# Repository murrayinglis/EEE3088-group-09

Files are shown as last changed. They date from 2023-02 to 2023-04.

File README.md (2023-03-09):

# EEE3088-group-09
Electrical Engineering Design Process

Group members: 
-Murray Inglis INGMUR002
-Tinashe Timba TMBTIN004
-Ankush Chohan CHHANK001

Description:
The analogue sensor is a battery sensor that will record the voltage of the battery via communicating with the STM ADC.
The digital sensor is a light sensor chip that communicates using I2C with the STM.

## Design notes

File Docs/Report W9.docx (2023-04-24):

EEE3088F 2023

Interim Design Report

Group 09 Light Sensor HAT

Ankush Chohan (CHHANK001)

Tinashe Timba (TMBTIN004)

Murray Inglis (INGMUR002)

23/04/2023

# 1 Executive Summary

The following report documents the design process and current design of a Light Sensor Discovery board HAT intended for use as a quality checker in glass manufacturing, water purification, and farming processes. Section 2 outlines these use cases in more detail along with the block system designed to meet the basic requirements. The schematic designs for the sub-modules can be found here: https://github.com/murrayinglis/EEE3088-group-09/tree/main/PCB/SCHEMATICS.

Technical specifications outlining the system requirements of the design and the related power consumption details are included in Section 3. An Agile process was followed to refine the project at each stage. Given the design, the device is capable of monitoring light intensity levels and managing the battery-powered system to ensure safety and long use.

For further details including licensing, reusing, and deploying; see the Github repository https://github.com/murrayinglis/EEE3088-group-09/blob/main/LICENSE.

# 2 Introduction

The team has designed a digital light sensor that works in conjunction with the STM32 microcontroller. It can be used to detect and monitor light intensity throughout the day and this data can be stored externally and be analysed for determining the light intensity conditions at the sensor’s location. The sensor can provide information such as the maximum and minimum light intensity experienced during the day. By placing the sensor at various conditions, the recorded data can be used to find the optimum location for a specific use.

The HAT will also have an analogue sensor that will measure the battery percentage of the device. This value can then be displayed on LEDs that are mounted on the board.

User role/Scenario1:

In a water purification plant, the water can be run through a glass tube with a light on one side and a light sensor on the other. Depending on the amount of light that passes through the water, the water quality can be gauged.

- A compact device that can be mounted on existing machinery.
- High accuracy reading to be generated for quality control purposes.
- Cost-effective solution. The cost of producing 5 of these boards is below USD70.

User role/Scenario2:

The device can be used to measure the quality of glass in a glass production line. Depending on the

value of light intensity that passes through a pane of glass, the glass can be categorized.

- User-friendly design that does not require technical training for employees.
- Robust design with low maintenance costs. The cost of producing 5 of these boards is below USD70.
- Takes readings at a fast rate to minimalize delays in production (5Hz).

User role/Scenario3

The device can be used by subsistence farmers to find the optimal position in their plot to grow specific varieties of plants depending on the lighting conditions that these plants thrive in. In this case the device will be placed out-doors therefore the onboard battery and battery level sensor will be useful.

- The device must be battery-powered as it will be placed outdoors far away from a power
- supply.
- Easy to move and set up.
- Efficient power consumption design switches certain modules into sleep mode when they are not being used.

## 2.1 Project Subsystems Block Diagram

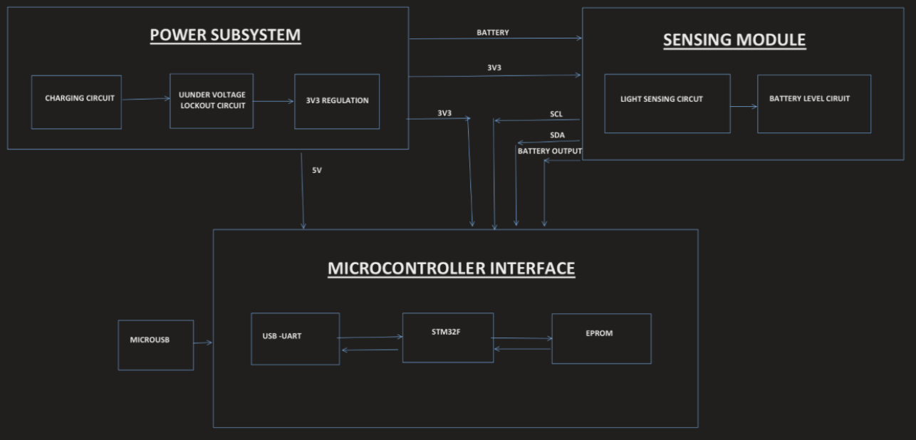
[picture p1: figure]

## 3 Specifications

## 3.1 Power subsystem submodule

Charging module:

IC used: TP4054-42

- Voltage input: 5V
- Voltage output to battery: 4.1V
- Current input: 0.5A
- Overcharge protection: regulates up to 18V down to 5V

Power supply to HAT:

3v3 Regulator IC used: AMS1117-3_3

- Voltage input from battery (4.1V-1V)
- Voltage output: 3.235V – 3.365V
- Current: 27mA
- Overcharge protection: regulates up to 18V down to 3.3V
- Schottky diode polarity protection
- Under voltage protection (1V lockout)

Conclusion:

Simulations of the under-voltage lockout circuit have shown lockout at around 1V which is too low a value for the HAT to operate. Additionally, the lockout level of the circuit is dependent on the load. Therefore, this circuit cannot be relied on until a physical test is done. The design, however is still safe due to the inclusion of intentional redundancy in the design. The under-voltage lockout circuit can be bypassed.

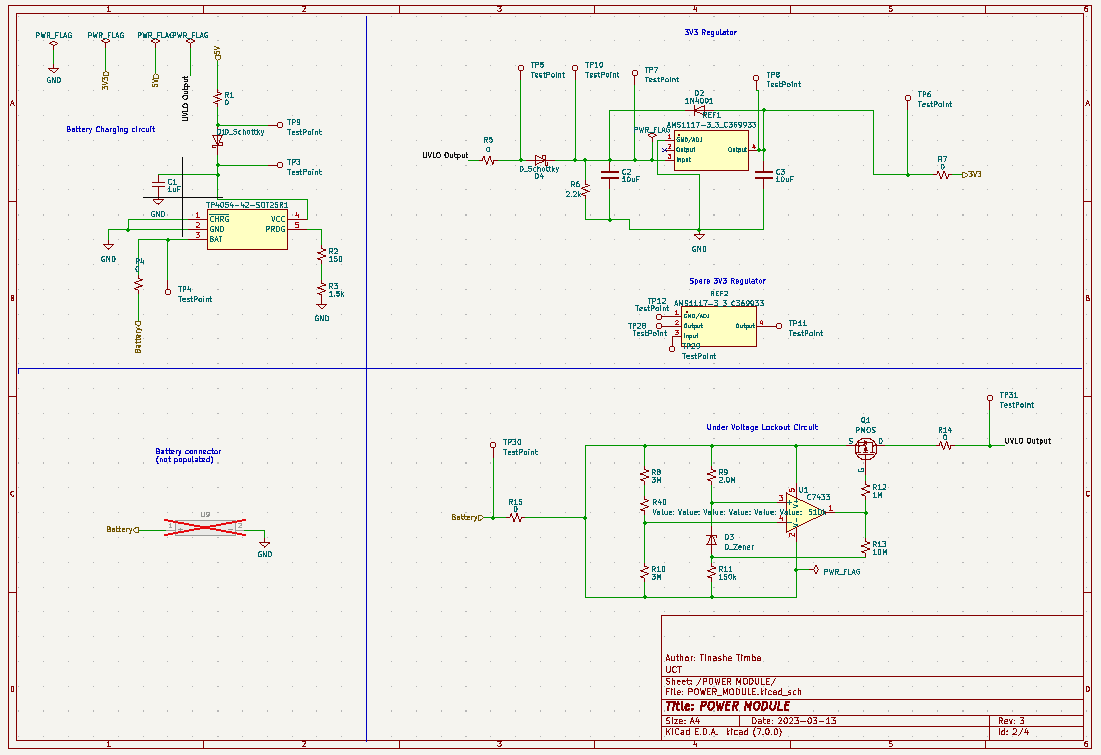
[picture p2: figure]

Figure 1: Power submodule https://github.com/murrayinglis/EEE3088-group-09/blob/main/PCB/SCHEMATICS/POWER_MODULE.kicad_sch.

## 3.2 Microcontroller interfacing submodule

Micro-usb:

- Name: USB 2.0 Surface Mount Female Micro-B SMD
- Part number: C404969
- Current rating: 1.8A
- Voltage rating: 30V

EEPROM:

IC used: AT24C256C-SSHL-T EEPROM

- Part number: C6482
- Operating voltage: 1.7V – 5.5V
- Operating read current: 1mA
- Operating write current: 3mA

USB to UART convertor:

IC used: CP2102-GMR

- Part number: C6568
- Operating voltage: 3V-3.6V
- Supply current: 200uA

Conclusion:

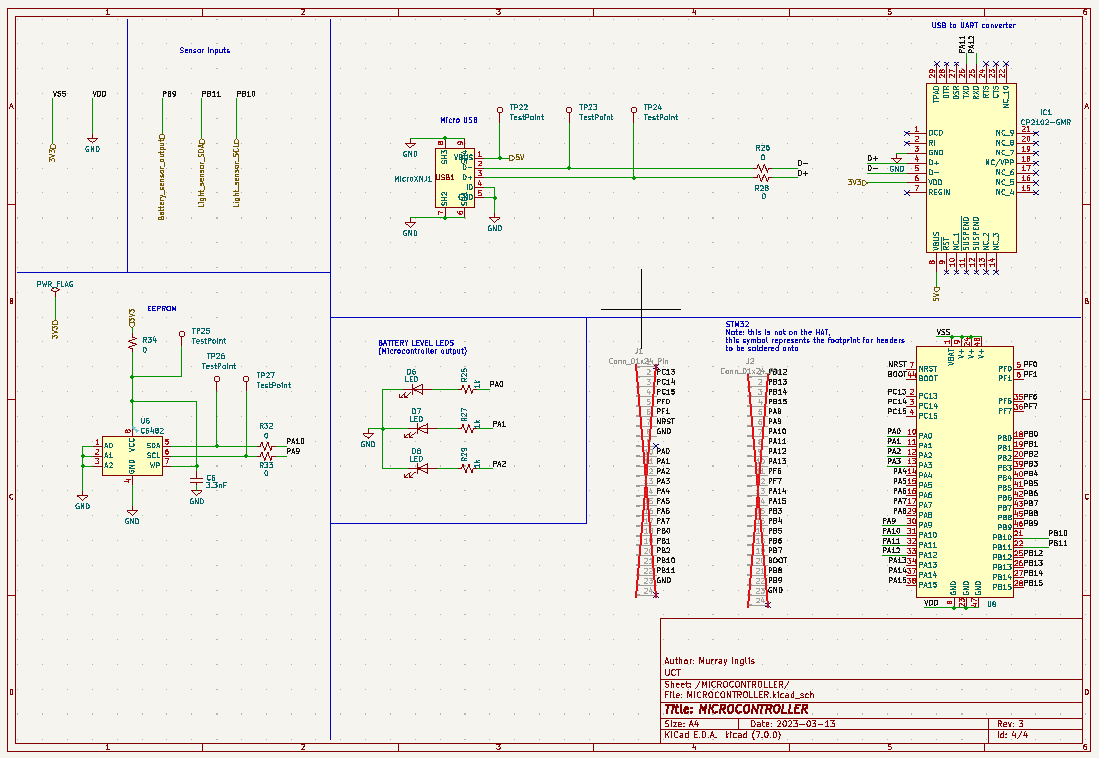
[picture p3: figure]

The team is satisfied with this submodule and believes that it has good design. There are no outstanding issues.

Figure 2: Microcontroller submodule https://github.com/murrayinglis/EEE3088-group-09/blob/main/PCB/SCHEMATICS/MICROCONTROLLER.kicad_sch

## 3.3 Sensing submodules

Digital optical sensor:

IC used: LTR-303ALS-01

- Supply voltage: 2.4V - 3.6V
- Interface bus supply voltage: 1.7V - 3.6V
- I2C Bus Input Pin High Voltage: 1.2V
- I2C Bus Input Pin Low Voltage: 0.6V
- Operating temperature: -30°C – 70°C
- Active supply current: 220uA
- Standby current: 5uA
- Initial startup time: 100ms
- Wakeup time from standby: 10ms

Analogue battery sensor:

- Input voltage from battery: 1V – 5V
- Output voltage: 0V - 2.5V
- Output current: 27mA

Conclusion:

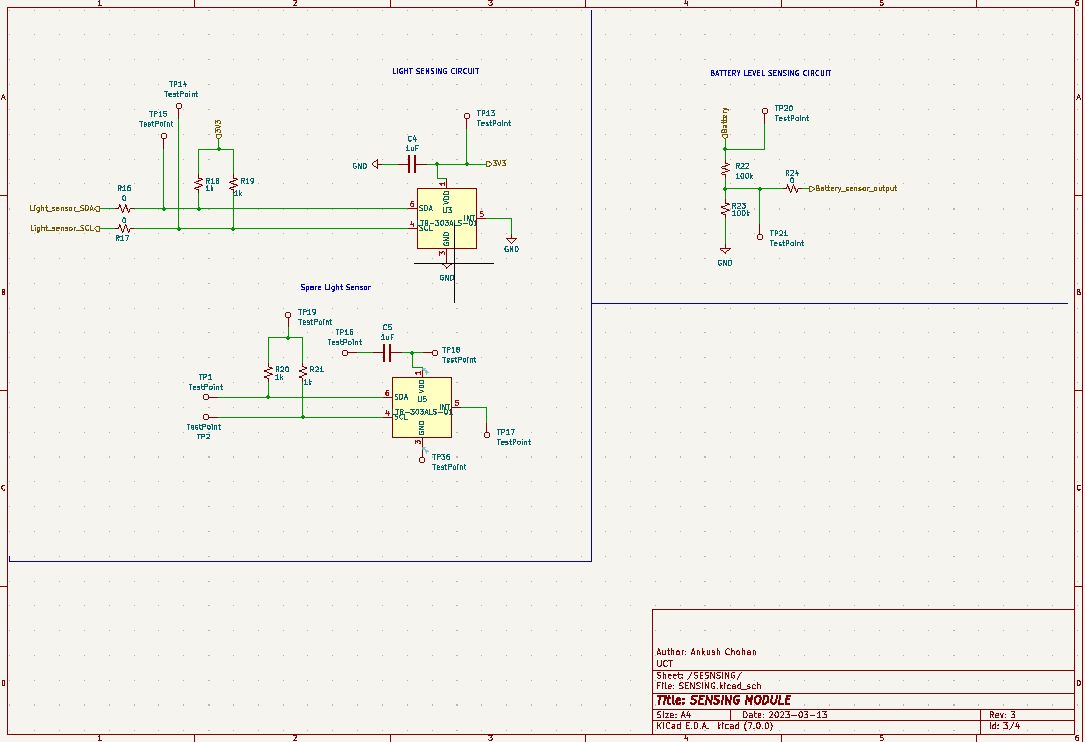
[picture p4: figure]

The team is satisfied with this submodule and believes that it has good design. There are no outstanding issues.

Figure 3: Sensing submodule https://github.com/murrayinglis/EEE3088-group-09/blob/main/PCB/SCHEMATICS/SENSING.kicad_sch.

# 4 Power Budgeting

## 4.1 Power submodule

Component | Supply Voltage (nominal V) | Minimum Current (mA) | Typical Current (mA) | Maximum Current (mA) | Minimum Power (mW) | Typical Power (mW) | Maximum Power (mW)
Battery charger (TP4054-42) | 5 | 0 | 0.150 | 0.500 | 0 | 0.75 | 2.5
Voltage regulator (AMS1117-3_3) | 4.8 | 900 | 1100 | 1500 | 4.32 | 5.28 | 7.2
Totals | | | | | 4.32 | 6.03 | 9.7

## 4.2 Microcontroller interfacing submodule

Component | Supply Voltage (nominal V) | Minimum Current (mA) | Typical Current (mA) | Maximum Current (mA) | Minimum Power (mW) | Typical Power (mW) | Maximum Power (mW)
FTDI (CP2102-GMR) | 3.3 | 0 | 20 | 26 | 0 | 66 | 85.8
EEPROM (AT24C256C) | 3.3 | 0 | 1 | 2 | 0 | 3.3 | 6.6
Totals | | | | | 0 | 69.3 | 92.1

## 4.3 Sensing submodules

Component | Supply Voltage (nominal V) | Minimum Current (mA) | Typical Current (mA) | Maximum Current (mA) | Minimum Power (mW) | Typical Power (mW) | Maximum Power (mW)
Light sensor (LTR-303ALS-01) | 3.3 | 0.005 | Not stated in the datasheet | 0.22 | 0.165 | NA | 0.726
Totals | | | | | 0.165 | | 0.726

Caveats:

For the battery sensor, there is no IC being used but power will be drawn by the voltage divider used to create a voltage for the STM32 ADC.

Additionally, the typical current for the light sensor IC was not stated in the datasheet, so the typical power could not be found.

4.4 System total

Submodule | Supply Voltage (nominal V) | Minimum Current (mA) | Typical Current (mA) | Maximum Current (mA) | Minimum Power (mW) | Typical Power (mW) | Maximum Power (mW)
PSU | 5 | | | | 4.32 | 6.03 | 9.7
Light sensor (LTR-303ALS-01) | 3.3 | 0.005 | N/A | 0.22 | 0.165 | NA | 0.726
Battery Level Sensor | 3.3 | 0 | - | - | - | - | -
Memory | 3.3 | 0 | 1 | 2 | 0 | 3.3 | 6.6
Microprocessor | 3.3 | - | - | 120 | - | - | 396
Totals | | | | | 4.485 | 9.33 | 413

# 5 Design Process

After brainstorming, the team settled on designing a HAT with a digital light sensor and an analogue battery level sensor. The decision was made due to the fact that the team believed this would be a simple and cost-effective approach to meet the basic requirements.

The team decided to use the LTR-303ALS-01 for the light sensor because it was one of the cheapest and had a large stock quantity. It also had clear application circuits.

The implementation of the battery level sensor was chosen to be a voltage divider to the STM32 ADC. This decision was made due to the implementation being simple and cheap.

The AT24C256C EEPROM was chosen because it was a basic part and had a large stock quantity.

The CP2102-GMR USB to UART converter (FTDI) chip was chosen because it was one of the cheapest USB to UART converters available on JLCPCB and it had a large stock quantity.

An inflection point the team encountered was that initially, the schematic included pin headers for the debugger, however after consultation with the assigned tutor, it was decided that it would be simpler and more effective to just use jumper cables to the debugger on the discovery board.

A problem that was encountered by the team was that all traces for the PCB were placed on the top layer. This led to a lack of space and an untidy board layout. Setting the bottom layer to a ground plane simplified this process, as well as using vias and tracks on the bottom plane.

During the design process, the team decided to include spare components on the HAT for redundancy. Seeing as the budget allowed for this and warnings were received that components from JLCPCB could be faulty or missing entirely.

# 6 Conclusion

In conclusion, the design requirements stated that a PCB with capabilities to handle and process information for 2 sensors where addressed by designing a HAT with a digital light-sensor (LTR-303ALS-01) and an analogue battery level sensor (voltage divider). These sensors were chosen as they were relatively simple and cost-effective to implement. The HAT works in conjunction with the STM32F microcontroller to perform the required tasks. Use cases for the HAT include product quality checking in glass manufacturing processes, and water purification processes as well as farming applications. The HAT takes in input from a USD which goes through a 3v3 regulator that supplies the rest of the components i.e the sensing module and microcontroller interface. Data is stored in the EPROM for reference and future use.

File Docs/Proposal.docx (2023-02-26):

Q1 Enviro sensing HAT Concept [5]

Describe what your HAT’s use case is, what it will attach to and in what scenario(s) someone would use it?

Light sensor that works in conjunction with the STM32 Board.

It can be used to detect and monitor light intensity throughout the day and this data can be stored externally and be analyzed for determining the light intensity conditions where the sensor is. This can provide information such as the maximum and minimum light intensity experienced during the day. By placing the sensor at various conditions, the recorded data can be used to find the optimum location for a specific use.

The HAT will also have a digital sensor which will measure the battery percentage of the device. This value can then be displayed on the LCD screen of the STM32 board.

Q2 Requirements [10]

The lecture discussed how one approach to capturing requirements is to think through the user stories that apply to a product/system/device. List 3 user stories that apply to your concept. These could be 3 different ways or reasons someone would use your HAT, eg 3 different situations it would be useful in, or even better would be if you can think of 3 different types of user and how they would use your HAT. Write down each use case scenario or user role and list at least 3 requirements derived from that role/scenario. The template shows 3x3 but put as many requirements and roles as you see.

User role/Scenario1:

In a water purification plant, the water can be run through a glass tube with a light on one side and a light sensor on the other. Depending on the amount of light that passes through the water, the water quality can be gauged.

- Compact
- High Accuracy
- Affordability

User role/Scenario2:

The device can be used to measure the quality of glass in a glass production line. Depending on the value of light intensity that passes through a pane of glass, the glass can be categorized.

- High Accuracy
- Affordability
- Robust

User role/Scenario3

The device can be used by subsistence farmers to find the optimal position in their plot to grow specific varieties of plant depending on the lighting conditions that there plants thrive in.

In this case the device will be placed out-doors therefore the onboard battery and battery level sensor will be useful.

- Battery Powered
- Robust
- Affordability

Q3 Project Subsystems Block Diagram [5]

Break development of the HAT into subsystems that can each be developed and tested independently. Provide a block diagram of your HAT indicating the subsystems and key modules/components within each here first. Provide sufficient labels on this diagram that another electrical engineer would be able to skim it and know what each modules’ primary function is, how they interface with each other/connect up and what the HAT as a whole does

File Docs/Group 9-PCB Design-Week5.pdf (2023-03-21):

## EEE3088F Week 5

### Murray Inglis – INGMUR002

### Tinashe Timba – TMBTIN004

### Ankush Chohan – CHHANK001

## Q1 Github [1]

https://github.com/murrayinglis/EEE3088-group-09

Branch: main

GERBER Files:

https://github.com/murrayinglis/EEE3088-group-09/tree/main/PCB/SCHEMATICS/GERBERS

## Q2 Power Subsystem Failure Management [2]

(i)

A duplicate of the 3.3V regulator chip will be included on the board, with test points at the pins of this chip and near the other chip. So if the other 3.3V regulator chip fails, the traces can be scratched or the chip can be removed from the board. The test points can be shorted and the duplicate chip can be used instead.

(ii)

Use thick traces: We have used 0.5mm traces to account for temperature changes and spaced as far possible.

Test points at either side of a trace so that if it’s damaged it can be shorted with a jumper.

(iii)

There are plenty of 3.3V regulator chips available on JLCPCB. One that is also a cheap, basic part and has a similar pinout to our regulator chip is the C14289. As of checking on 13/03/2023 it has 152575 in stock.

(iv)

Test points so components or certain modules in the circuit can be tested or shorted to remove them from the circuit. The test points are placed at the power input, ground and other inputs and outputs of the circuit in order. This is to account for the component not working or parts of the module circuitry not working.

## Q3 Sensing Subsystem Failure Management [2]

(i)

For the light sensor chip, add a duplicate of the sensor chip with traces to the microcontroller. However, leave out power traces. If the original sensor fails, jumper cables can be used to power this sensor and the traces to the original sensor’s power can be scratched out.

For the battery, the voltage divider resistances may be incorrect or the voltage divider isn’t working as intended. If this occurs, an external resistor voltage divider network can be used and connected using jumper cables. Test points are included at the voltage divider to add this circuit.

Guard traces to prevent interference at the sensor output.

(ii)

Use thick traces to account for temperature changes and spaced as far possible.

Test points at either side of a trace so that if it’s damaged it can be shorted with a jumper.

(iii)

There are plenty of light sensor chips available on JLCPCB. One that has a similar pinout to our light sensor chip is the BH1750FVI. As of checking on 13/03/2023 it has 1202 in stock.

(iv)

Test points so components or certain modules in the circuit can be tested or shorted to remove them from the circuit. The test points are placed at the power input, ground and other inputs and outputs of the circuit in order. This is to account for the component not working or parts of the module circuitry not working.

## Q4 Microcontroller interfacing Failure Management [2]

(i)

A duplicate of the EEPROM will be included on the board, with test points at the pins of this chip and near the other chip. So if the other 3.3V regulator chip fails, the traces can be scratched or the chip can be removed from the board. The test points can be shorted and the duplicate chip can be used instead.

(ii)

Use thick traces to account for temperature changes and spaced as far possible.

Test points at either side of a trace so that if it’s damaged it can be shorted with a jumper.

(iii)

We have found another EEPROM (C7562) with very similar specifications and the same pinout as the one we designed our circuit around (C6482). This backup component is a cheap, basic part and as of checking on 09/03/2023 it has 32937 in stock.

(iv)

Test points so components or certain modules in the circuit can be tested or shorted to remove them from the circuit. The test points are placed at the power input, ground and other inputs and outputs of the circuit in order. This is to account for the component not working or parts of the module circuitry not working.

## Q5 Power Subsystem Schematic [2]

The updated schematic for the power subsystem includes the battery holder (which will be “Do Not Populate” on the board). The battery holder is needed as a power source for the ERCs.

Power flags are also included for labelling GND and power sources for passing the ERCs.

The schematic symbol for the 3V3 regulator was changed to match the footprint.

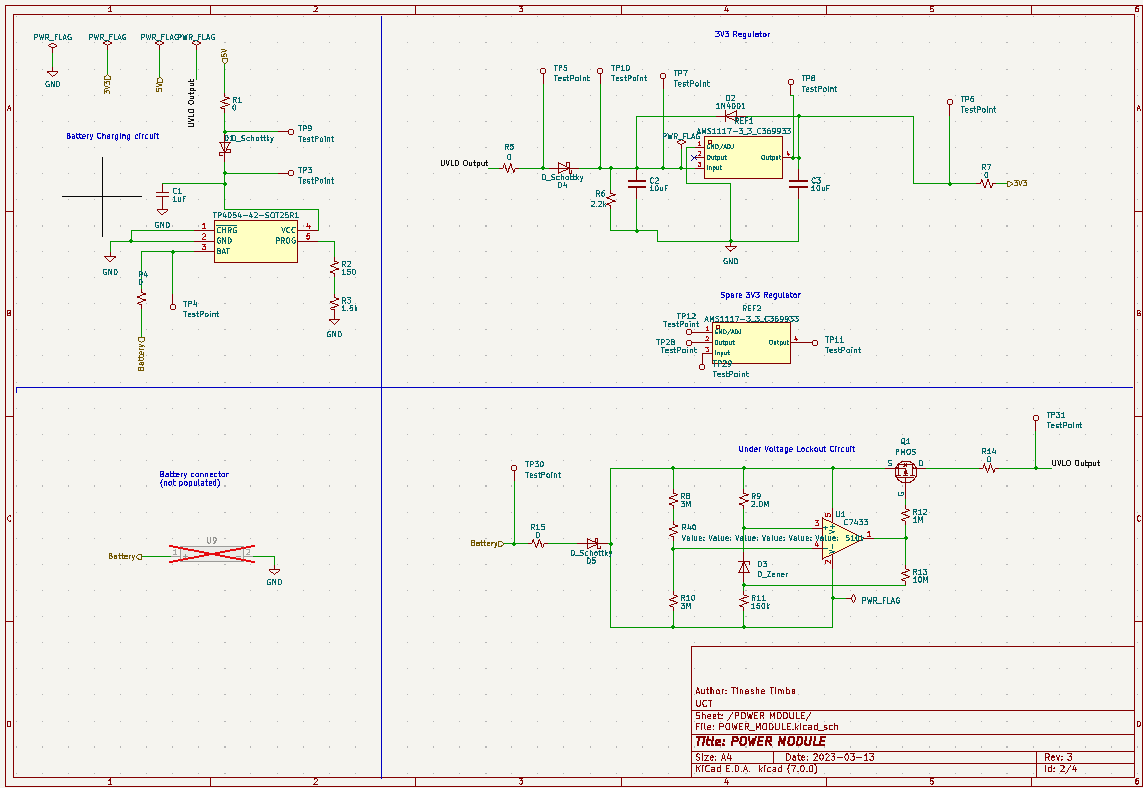
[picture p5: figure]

## Q6 Sensing Subsystem Schematic [2]

No changes made.

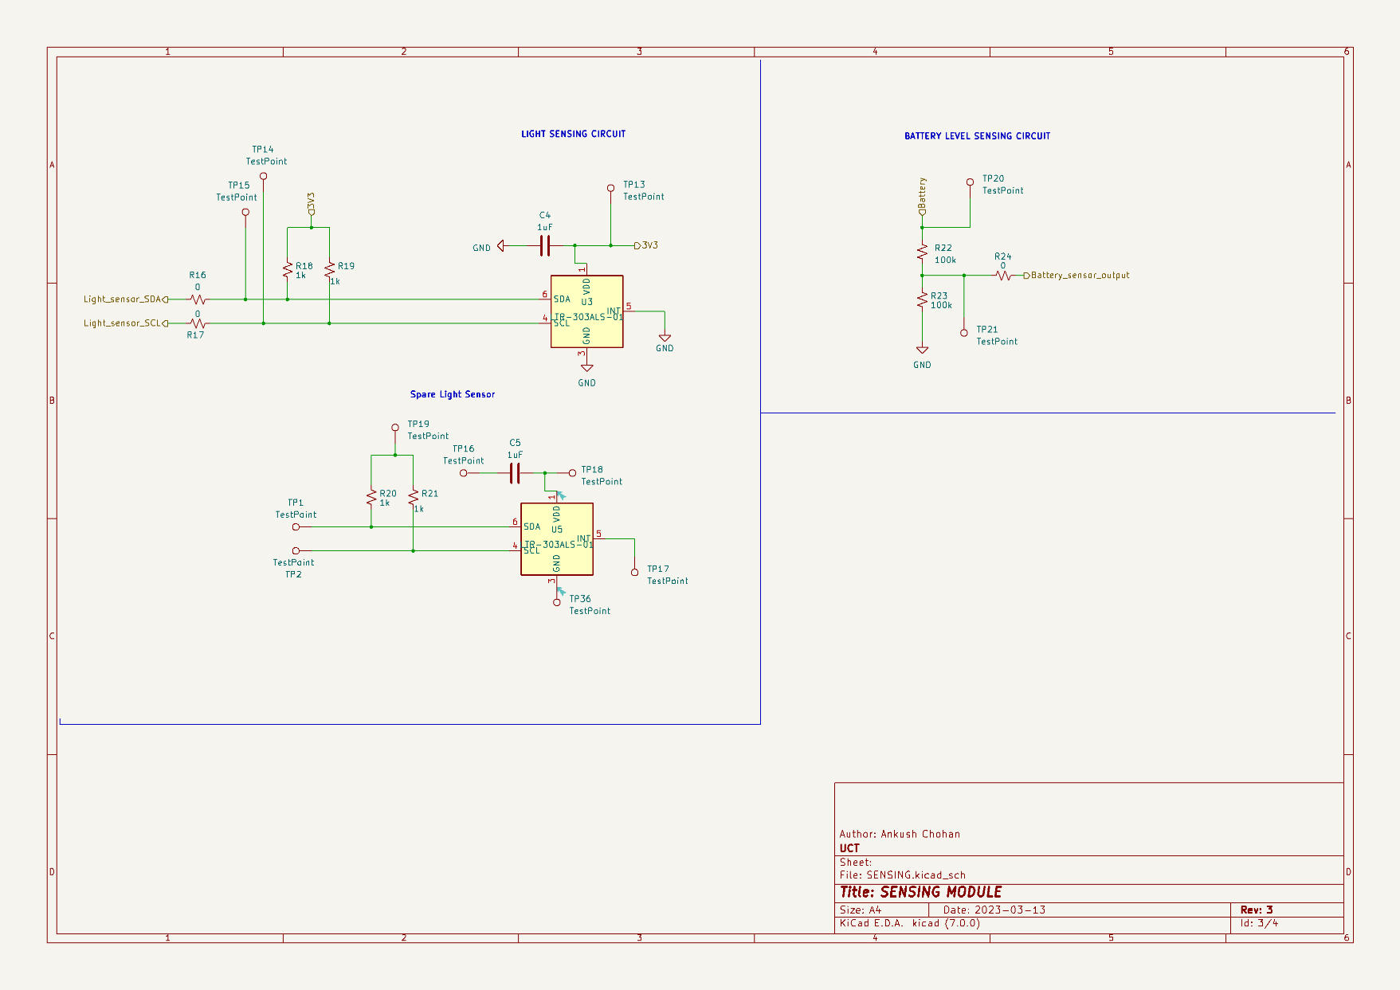
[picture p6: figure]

## Q7 Microcontroller interfacing Schematic [2]

Added the symbol for the microcontroller and headers. These are both “Do Not Populate”. The symbol is only there so that the footprint is printed onto the PCB.

The 1x24 connectors were added to allow jumper cables to easily be connected to the STM. The connectors themselves are “Do not populate” as we will solder them on ourselves once the board is made.

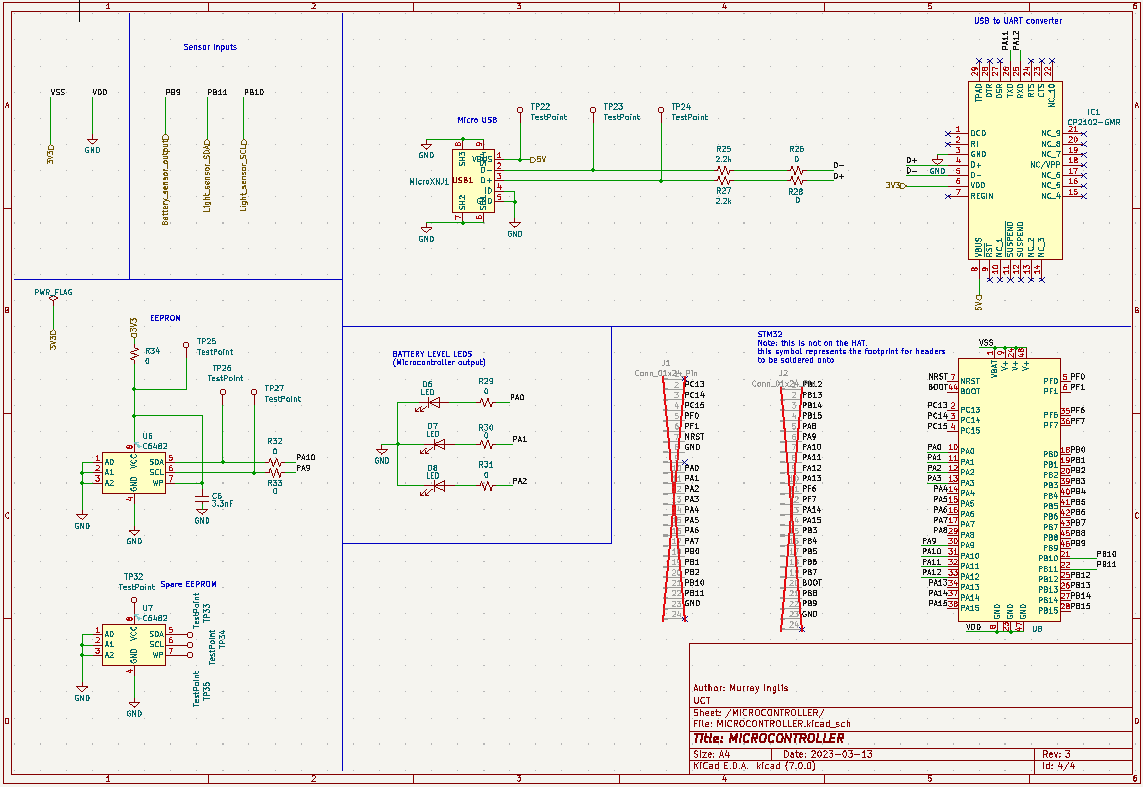
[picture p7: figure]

## Q8 Updated ERCs [2]

- Short circuit detection
- Open circuit detection
- Unconnected pin detection
- Clearance checks
- Net list comparison

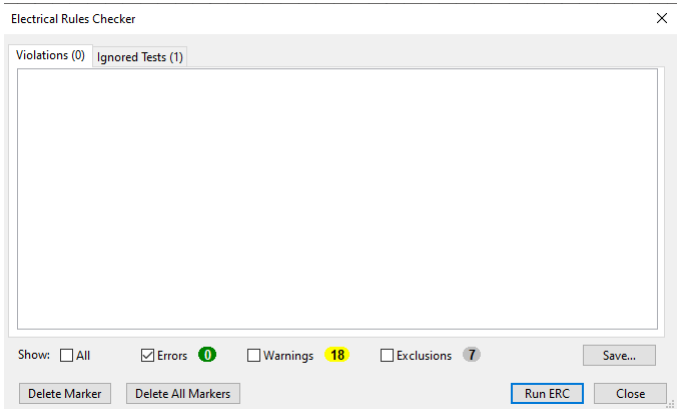
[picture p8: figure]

Note: the exclusions were for the spare components that we included that are only connected to test points.

## Q9 DRCs [2]

- Clearance checks
- Minimum track width checks
- Silkscreen checks
- Hole size checks
- Mask-to-pad clearance checks
- Solder mask expansion checks

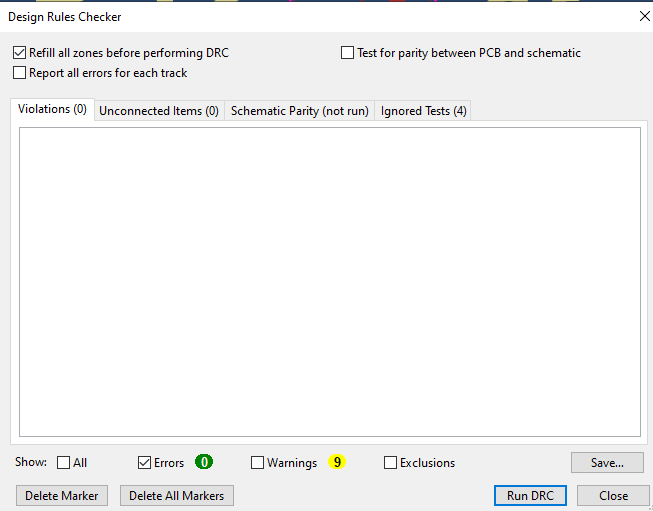
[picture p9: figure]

## Q10 Updated BOM [5]

https://github.com/murrayinglis/EEE3088-group-09/blob/main/PCB/SCHEMATICS/BOM.xlsx

Reference | Value | Extended | LCSC | Unit
price | Qty Total
C1, C4, C5 | 1uF | | C28323 | 0,0058 | 3 | 0,0174
C2, C3 | 10uF | | C19702 | 0,0066 | 2 | 0,0132
C6 | 3.3nF | | C1613 | 0,0058 | 1 | 0,0058
D1, D4, D5 | D_Schottky | | C191023 | 0,0167 | 3 | 0,0501
D2 | 1N4001 | | C64898 | 0,0071 | 1 | 0,0071
D3 | D_Zener | | C8056 | 0,0111 | 1 | 0,0111
D6-D8 | LED | | C2286 | 0,0054 | 3 | 0,0162
IC1 | CP2102-GMR | | C6568 | 2,3774 | 1 | 2,3774
MicroXNJ1 | | YES | C404969 | 0,0333 | 1 | 0,0333
Q1 | PMOS | YES | C2959854 | 0,0851 | 1 | 0,0851
R1, R4, R5, R7, R14-R17, R24, R26, R28-
R34 | 0 | | C17168 | 0,0005 | 17 | 0,0085
R2 | 150 | | C22808 | 0,001 | 1 | 0,001
R3 | 1.5k | | C25867 | 0,0005 | 1 | 0,0005
R6, R25, R27 | 2.2k | | C17520 | 0,0017 | 3 | 0,0051
R8, R10 | 3M | | C23156 | 0,0013 | 2 | 0,0026
R9 | 2.0M | | C22976 | 0,0016 | 1 | 0,0016
R11 | 150k | | C22807 | 0,001 | 1 | 0,001
R12 | 1M | | C17927 | 0,0031 | 1 | 0,0031
R13 | 10M | | C26108 | 0,0024 | 1 | 0,0024
R18-R21 | 1k | | C11702 | 0,0005 | 4 | 0,002
R22, R23 | 100k | | C17900 | 0,003 | 2 | 0,006
R40 | 510k | | C11616 | 0,0005 | 1 | 0,0005
REF1, REF2 | AMS1117-3_3_C369933 | YES | C369933 | 0,0646 | 2 | 0,1292
TP4054-42-SOT25R1 | | | C32574 | 0,1433 | 1 | 0,1433
U1 | C7433 | | C7433 | 0,2804 | 1 | 0,2804
U3, U5 | LTR-303ALS-01 | YES | C364577 | 0,3887 | 2 | 0,7774
U6, U7 | EPROM | YES | C6482 | 0,4906 | 2 | 0,9812
TOTAL | | | | | | 4,9625
| Including the cost for 5 boards and for the 5 extended parts:

Total budget:

4.9625*5 + 3*5 = $39.8125

## Q11 PCB [15]

Front layout and routing

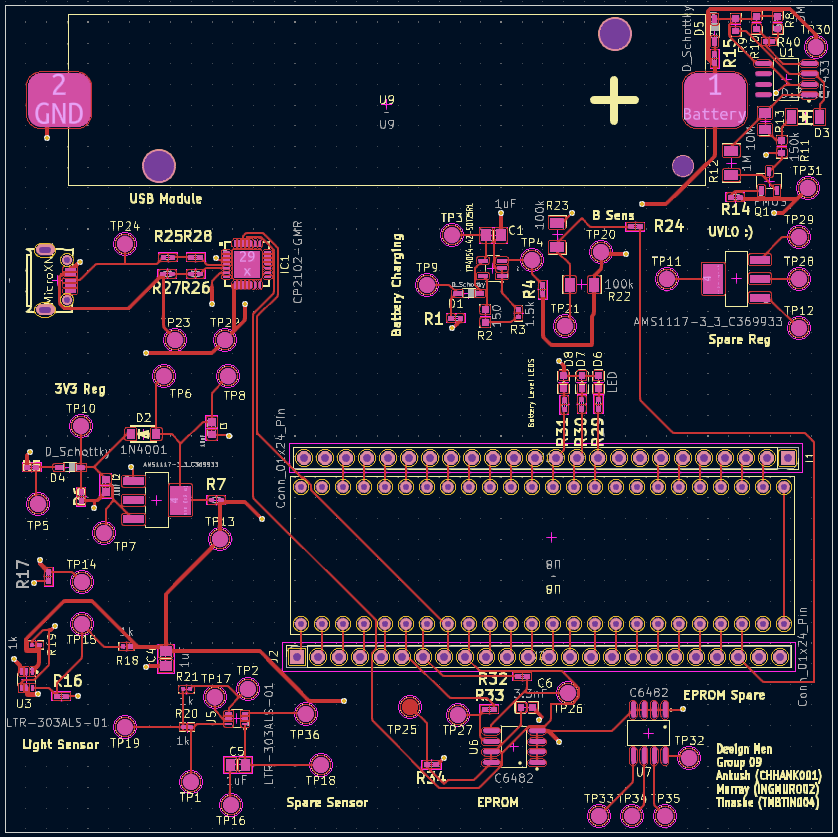
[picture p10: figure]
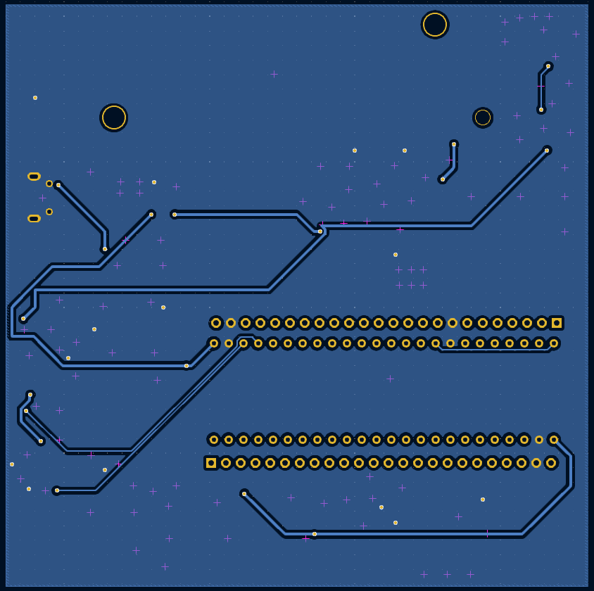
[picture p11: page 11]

Back copper routing

SilkScreen

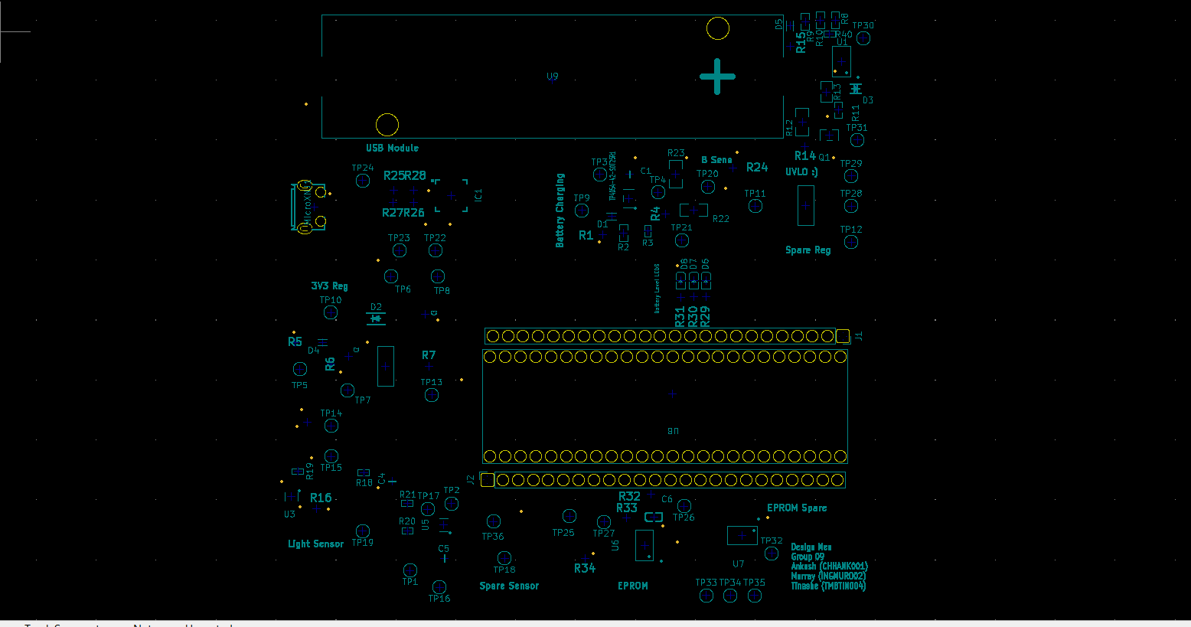
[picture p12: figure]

3D image

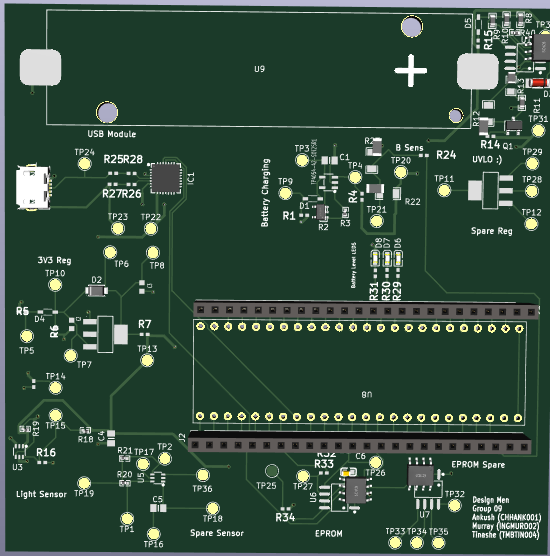
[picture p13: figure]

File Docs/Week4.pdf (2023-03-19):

## EEE3088F Week 4

### Murray Inglis – INGMUR002

### Tinashe Timba – TMBTIN004

### Ankush Chohan – CHHANK001

## Q1 Github [1]

https://github.com/murrayinglis/EEE3088-group-09

## Q2 Power Subsystem Failure Management [5]

(i)

A duplicate of the 3.3V regulator chip will be included on the board, with test points at the pins of this chip and near the other chip. So if the other 3.3V regulator chip fails, the traces can be scratched or the chip can be removed from the board. The test points can be shorted and the duplicate chip can be used instead.

(ii)

Use thick traces to account for temperature changes and spaced as far possible.

Test points at either side of a trace so that if it’s damaged it can be shorted with a jumper.

(iii)

There are plenty of 3.3V regulator chips available on JLCPCB. One that is also a cheap, basic part and has a similar pinout to our regulator chip is the C14289. As of checking on 13/03/2023 it has 152575 in stock.

(iv)

Test points so components or certain modules in the circuit can be tested or shorted to remove them from the circuit.

## Q3 Sensing Subsystem Failure Management [5]

(i)

For the light sensor chip, add a duplicate of the sensor chip with traces to the microcontroller. However, leave out power traces. If the original sensor fails, jumper cables can be used to power this sensor and the traces to the original sensor’s power can be scratched out.

For the battery, the voltage divider resistances may be incorrect or the voltage divider isn’t working as intended. If this occurs, an external resistor voltage divider network can be used and connected using jumper cables. Test points are included at the voltage divider to add this circuit.

Guard traces to prevent interference at the sensor output.

(ii)

Use thick traces to account for temperature changes and spaced as far possible.

Test points at either side of a trace so that if it’s damaged it can be shorted with a jumper.

(iii)

There are plenty of light sensor chips available on JLCPCB. One that has a similar pinout to our light sensor chip is the BH1750FVI. As of checking on 13/03/2023 it has 1202 in stock.

(iv)

Test points so components or certain modules in the circuit can be tested or shorted to remove them from the circuit.

## Q4 Microcontroller interfacing Failure Management [5]

(i)

A duplicate of the EEPROM will be included on the board, with test points at the pins of this chip and near the other chip. So if the other 3.3V regulator chip fails, the traces can be scratched or the chip can be removed from the board. The test points can be shorted and the duplicate chip can be used instead.

(ii)

Use thick traces to account for temperature changes and spaced as far possible.

Test points at either side of a trace so that if it’s damaged it can be shorted with a jumper.

(iii)

We have found another EEPROM (C7562) with very similar specifications and the same pinout as the one we designed our circuit around (C6482). This backup component is a cheap, basic part and as of checking on 09/03/2023 it has 32937 in stock.

(iv)

Test points so components or certain modules in the circuit can be tested or shorted to remove them from the circuit.

## Q5 Power Subsystem Schematic [10]

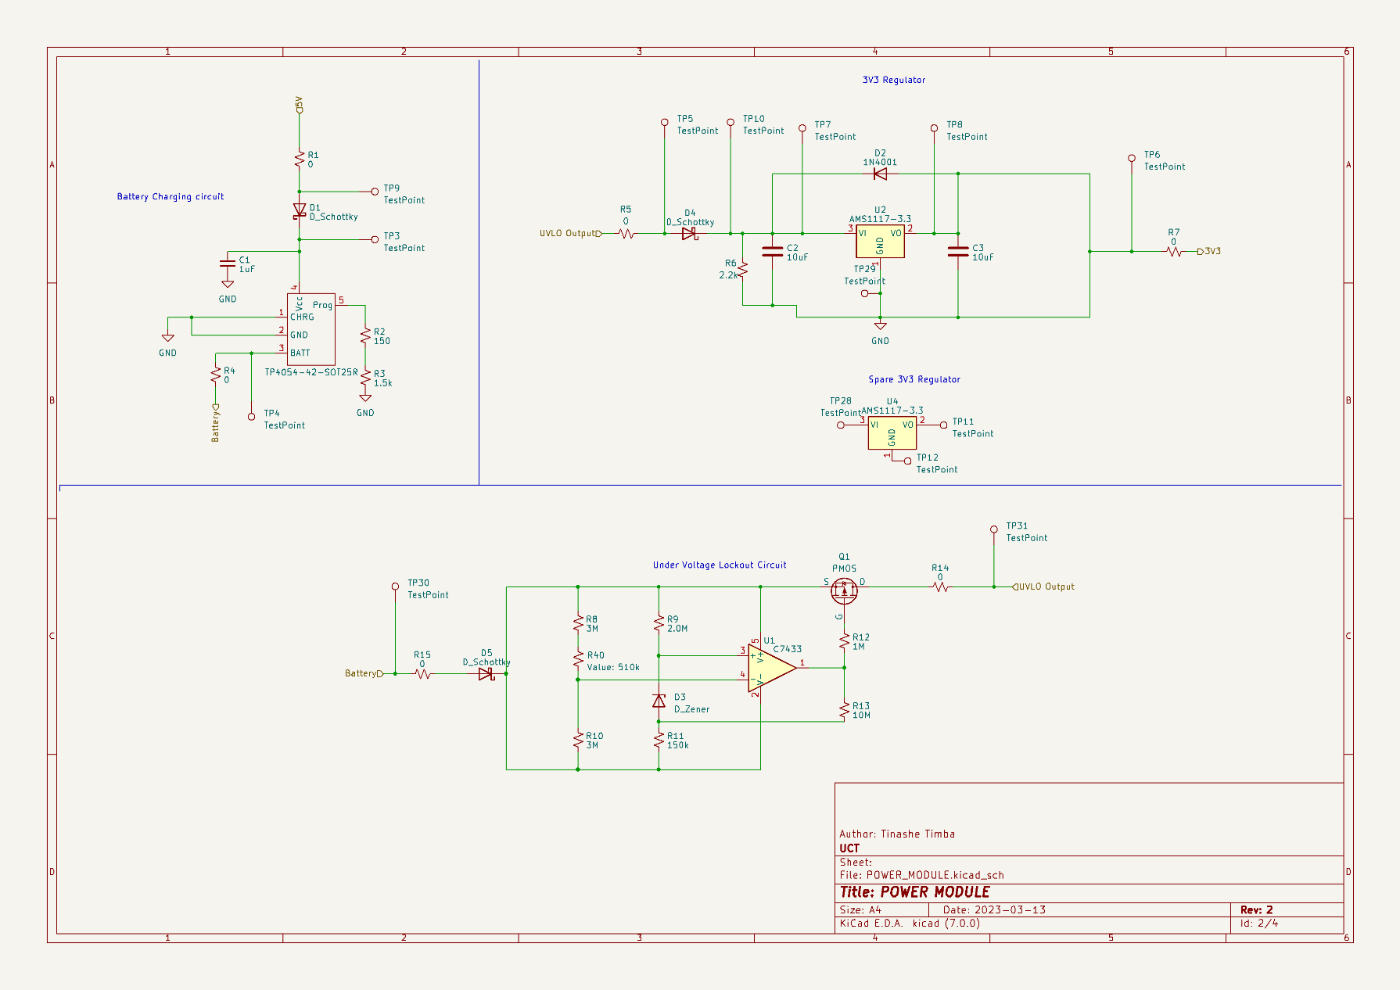
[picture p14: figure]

## Q6 Sensing Subsystem Schematic [10]

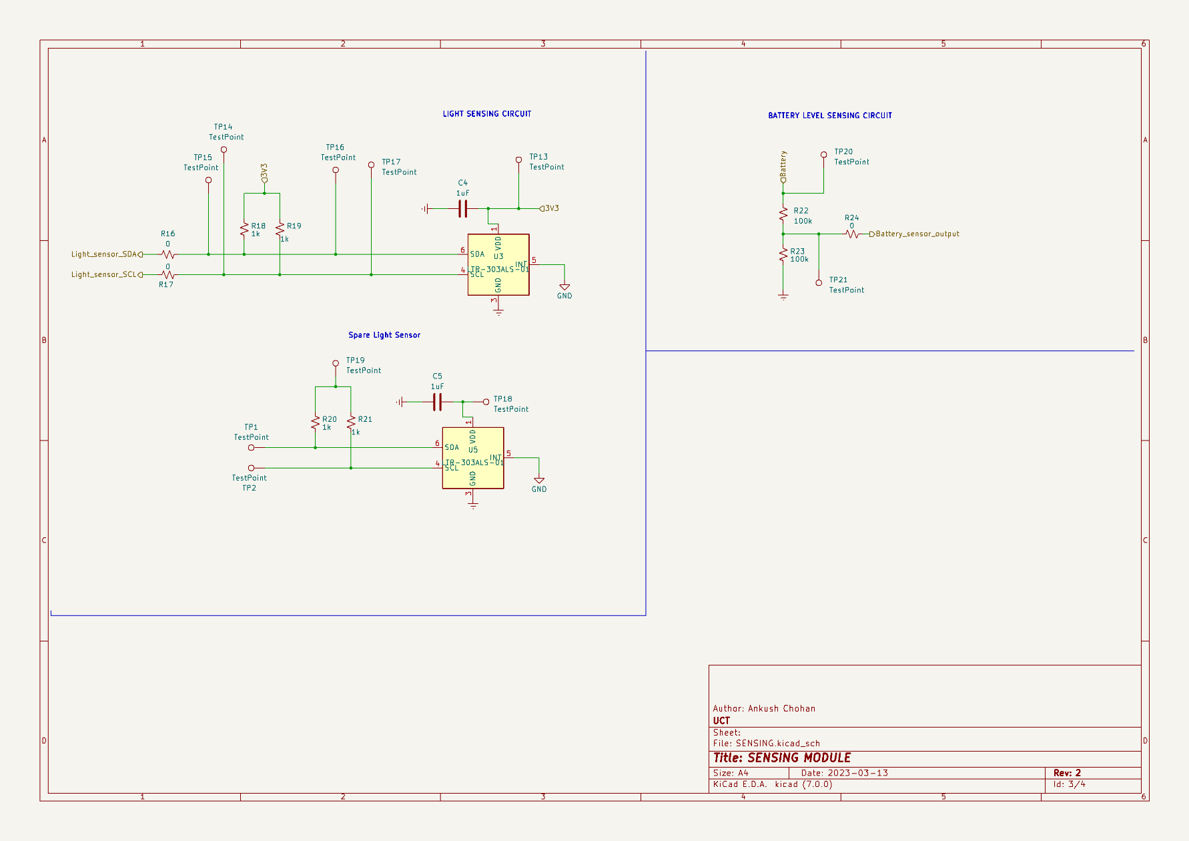
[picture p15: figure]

## Q7 Microcontroller interfacing Schematic [10]

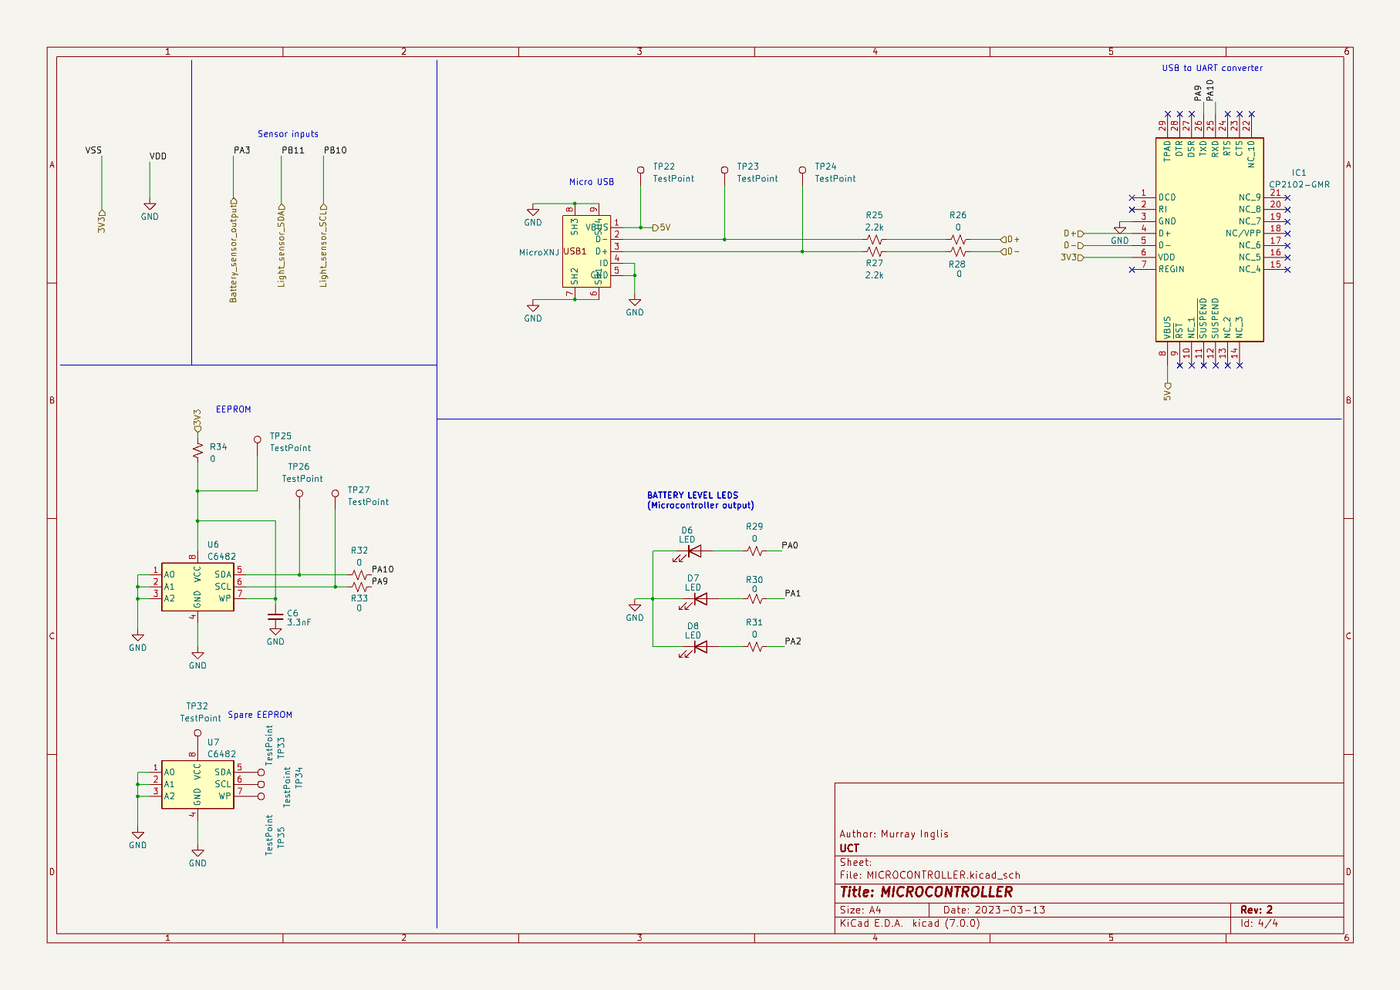
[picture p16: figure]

## Q8 Planned ERCs [5]

- Short circuit detection
- Open circuit detection
- Unconnected pin detection
- Clearance checks
- Net list comparison

## Q9 Updated BOM [4]

https://github.com/murrayinglis/EEE3088-group-09/blob/main/PCB/SCHEMATICS/BOM.xlsx

Reference | Value | Extended Part

Unit
price
C1, C4, C5 | 1uF | | C28323 | 0,0058
C2, C3 | 10uF | | C19702 | 0,0066
C6 | 3.3nF | | C1613 | 0,0058
D1, D4, D5 | D_Schottky | C191023 0,0167
D2 | 1N4001 | | C95872 | 0,0069
D3 | D_Zener | | C8056 | 0,0111
D6-D8 | LED | | C2286 | 0,0054
MicroXNJ? | YES | C404969 0,0333
Q1 | PMOS | | C20917 | 0,0864
R1, R4, R5, R7, R14-R17, R24, R26, R28-
R39 | 0 | | C4177 | 0,0012
R2 | 150 | | C22808 | 0,001
R3 | 1.5k | | C25867 | 0,0005
R6, R25, R27 | 2.2k | | C17520 | 0,0017
R8, R10 | 3M | | C23156 | 0,0013
R9 | 2.0M | | C22976 | 0,0016
R11 | 150k | | C22807 | 0,001
R12 | 1M | | C17927 | 0,0031
R13 | 10M | | C26108 | 0,0024
R18-R21 | 1k | | C11702 | 0,0005
R22, R23 | 100k | | C17900 | 0,003
R40 | 510k | | C11616 | 0,0005
TP4054-42-SOT25R? | | | C32574 | 0,1433
U1 | C7433 | | C7433 | 0,2804
U2, U4 | AMS1117-3.3 | YES | C369933 0,0627
U3, U5 | LTR-303ALS-01 | YES | C364577 0,3887
IC1 | CP2102-GMR | | C6568 | 2,3774
U6,U7 | C6482 | YES | C6482 | 0,5172
TOTAL | | | | 3,9655

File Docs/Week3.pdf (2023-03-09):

### Q1 Power subsystem

Q1.1 Specification
Charging module:
- Voltage input: 5V
- Voltage output to battery: 4.1V
- Current input: 0.5A
- Overcharge protection: regulates up to 18V down to 5V

Power supply:

- Voltage: 3.235V – 3.365V
- Current: 27mA
- Overcharge protection: regulates up to 18V down to 3.3V
- Schottky diode polarity protection
- Zener diode undercharge protection

Q1.2 Draft BOM

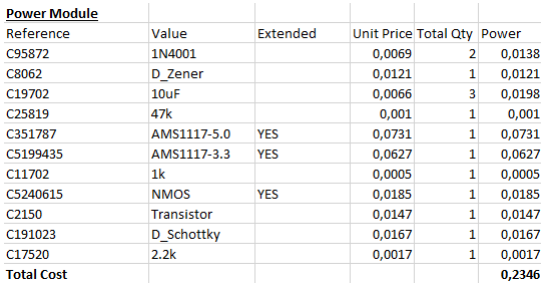
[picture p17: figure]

With the extra $3 for each extended part, the total cost is $9.2346.

https://github.com/murrayinglis/EEE3088-group-09/blob/main/PCB/SCHEMATICS/BOM.xlsx

Q1.3 Interfacing
- STM32 - providing power at 3.3V.
- HAT - providing power to the circuitry at 3.3V.
- Battery level sensor – outputs battery voltage.
- Battery - drawing power
- Battery - charging

### Q2 Microcontroller interfacing

Q2.1 Specification
Micro-usb:
- Name: USB 2.0 Surface Mount Female Micro-B SMD
- Part number: C404969
- Current rating: 1.8A
- Voltage rating: 30V

EEPROM:

- Name: HX24LC02B EEPROM
- Part number: C2987267
- Operating voltage: 1.7V – 5.5V
- Operating read current: 1mA
- Operating write current: 3mA

Q2.2 Draft BOM

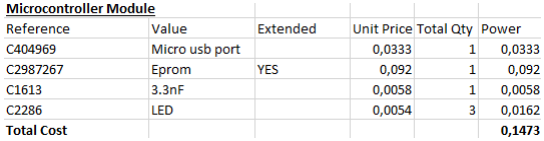
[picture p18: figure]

With the extra $3 for each extended part, the total cost is $3,1473.

https://github.com/murrayinglis/EEE3088-group-09/blob/main/PCB/SCHEMATICS/BOM.xlsx

Q2.3 Interfacing
- Battery to draw power.
- Analogue sensor to ADC pin of the STM (pin VBAT).
- The digital sensor to I2C pins of the STM (pins PB10 and PB11).
- Debugger on pins NRST, T_SWCLK, T_SWDIO.
- EEPROM on pins PA9 and PA10
- FTDI serial header on pins PA7, PA8, PA11.

### Q3 Sensing

Q3.1.1 Digital Sensor Specification Optical sensor:

- Name: LTR-303ALS-01
- Supply voltage: 2.4V - 3.6V
- Interface bus supply voltage: 1.7V - 3.6V
- I2C Bus Input Pin High Voltage: 1.2V
- I2C Bus Input Pin Low Voltage: 0.6V
- Operating temperature: -30°C – 70°C
- Active supply current: 220uA
- Standby current: 5uA
- Initial startup time: 100ms
- Wakeup time from standby: 10ms

Q3.1.2 Analogue Sensor Specification Battery sensor:

- Output voltage: 0V - 2.5V
- Output current: 27mA

Q3.2 Draft BOM

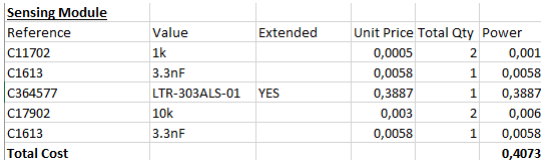
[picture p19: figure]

With the extra $3 for each extended part, the total cost is $3,4073.

https://github.com/murrayinglis/EEE3088-group-09/blob/main/PCB/SCHEMATICS/BOM.xlsx

Q3.3 Interfacing

Q3.1.1 Digital Sensor Interfacing
- STM on pins PB10 and PB11
- 3.3V from power supply

Q3.1.2 Analogue Sensor Interfacing
- STM on pin VBAT
- Battery voltage from battery

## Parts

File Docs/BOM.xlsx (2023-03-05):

Reference | Value | Footprint | Datasheet | Extended | Sim.Device | Sim.Pins | Sim.Type | Total | Unit Price | Total Qty | Power
C1613 | 3.3nF |  | ~ |  |  |  |  |  | 0.0058
C2286 | LED |  | ~ |  |  |  |  |  | 0.0054 | 1
C8062 | D_Zener |  | ~ |  |  |  |  |  | 0.0121 | 1
C11702 | -- mixed values -- |  | ~ |  |  |  |  |  | 0.0005 | 1
C17520 | 2.2k |  | ~ |  |  |  |  |  | 0.0017 | 1
C17902 | 10k |  | ~ |  |  |  |  |  | 0.003 | 1
C19702 | 10uF |  | ~ |  |  |  |  |  | 0.0066 | 1
C28323 | 1uF |  | ~ |  |  |  |  |  | 0.0087 | 1
C95872 | 1N4001 | Diode_THT:D_DO-41_SOD81_P10.16mm_Horizontal | http://www.vishay.com/docs/88503/1n4001.pdf |  | D | 1=K 2=A |  |  | 0.0069 | 1
C191023 | D_Schottky |  | ~ |  |  |  |  |  | 0.0167 | 1
C404969 |  |  |  |  |  |  |  |  | 0.0333 | 1
C5240615 | NMOS |  | https://ngspice.sourceforge.io/docs/ngspice-manual.pdf | YES | NMOS | 1=D 2=G 3=S | VDMOS |  | 0.0185 | 1
Q2 | C2150 |  | ~ |  | NPN | 1=C 2=B 3=E | GUMMELPOON |  | 0.0147 | 1
C25819 | 47k |  | ~ |  |  |  |  |  | 0.001 | 1
U1 | AMS1117-5.0 | Package_TO_SOT_SMD:SOT-223-3_TabPin2 | http://www.advanced-monolithic.com/pdf/ds1117.pdf | YES |  |  |  |  | 0.0731 | 1
U2 | AMS1117-3.3 | Package_TO_SOT_SMD:SOT-223-3_TabPin2 | http://www.advanced-monolithic.com/pdf/ds1117.pdf | YES |  |  |  |  | 0.0627 | 1
U3 | LTR-303ALS-01 | OptoDevice:Lite-On_LTR-303ALS-01 | http://optoelectronics.liteon.com/upload/download/DS86-2013-0004/LTR-303ALS-01_DS_V1.pdf | YES |  |  |  |  | 0.3887 | 1
U4, U7 |  |  |  |  |  |  |  |  |  | 2
U6 | C2987267 |  | http://ww1.microchip.com/downloads/en/DeviceDoc/21710J.pdf | YES |  |  |  |  | 0.092 | 1
V1 |  |  | ~ |  | V | 1=+ 2=- | DC |  |  | 1
Power Module
C95872 | 1N4001 | Diode_THT:D_DO-41_SOD81_P10.16mm_Horizontal | http://www.vishay.com/docs/88503/1n4001.pdf |  | D | 1=K 2=A |  |  | 0.0069 | 2 | 0.0138
C8062 | D_Zener |  | ~ |  |  |  |  |  | 0.0121 | 1 | 0.0121
C19702 | 10uF |  | ~ |  |  |  |  |  | 0.0066 | 3 | 0.0198
C25819 | 47k |  | ~ |  |  |  |  |  | 0.001 | 1 | 0.001
C351787 | AMS1117-5.0 | Package_TO_SOT_SMD:SOT-223-3_TabPin2 | http://www.advanced-monolithic.com/pdf/ds1117.pdf | YES |  |  |  |  | 0.0731 | 1 | 0.0731
C5199435 | AMS1117-3.3 | Package_TO_SOT_SMD:SOT-223-3_TabPin2 | http://www.advanced-monolithic.com/pdf/ds1117.pdf | YES |  |  |  |  | 0.0627 | 1 | 0.0627
C11702 | 1k |  | ~ |  |  |  |  |  | 0.0005 | 1 | 0.0005
C5240615 | NMOS |  | https://ngspice.sourceforge.io/docs/ngspice-manual.pdf | YES | NMOS | 1=D 2=G 3=S | VDMOS |  | 0.0185 | 1 | 0.0185
C2150 | Transistor |  | ~ |  | NPN | 1=C 2=B 3=E | GUMMELPOON |  | 0.0147 | 1 | 0.0147
C191023 | D_Schottky |  | ~ |  |  |  |  |  | 0.0167 | 1 | 0.0167
C17520 | 2.2k |  | ~ |  |  |  |  |  | 0.0017 | 1 | 0.0017
Total Cost |  |  |  |  |  |  |  |  |  |  | 0.2346
Sensing Module
C11702 | 1k |  | ~ |  |  |  |  |  | 0.0005 | 2 | 0.001
C1613 | 3.3nF |  | ~ |  |  |  |  |  | 0.0058 | 1 | 0.0058
C364577 | LTR-303ALS-01 | OptoDevice:Lite-On_LTR-303ALS-01 | http://optoelectronics.liteon.com/upload/download/DS86-2013-0004/LTR-303ALS-01_DS_V1.pdf | YES |  |  |  |  | 0.3887 | 1 | 0.3887
C17902 | 10k |  | ~ |  |  |  |  |  | 0.003 | 2 | 0.006
C1613 | 3.3nF |  | ~ |  |  |  |  |  | 0.0058 | 1 | 0.0058
Total Cost |  |  |  |  |  |  |  |  |  |  | 0.4073
Microcontroller Module
C404969 | Micro usb port |  |  |  |  |  |  |  | 0.0333 | 1 | 0.0333
C2987267 | Eprom |  | http://ww1.microchip.com/downloads/en/DeviceDoc/21710J.pdf | YES |  |  |  |  | 0.092 | 1 | 0.092
C1613 | 3.3nF |  | ~ |  |  |  |  |  | 0.0058 | 1 | 0.0058
C2286 | LED |  | ~ |  |  |  |  |  | 0.0054 | 3 | 0.0162
Total Cost |  |  |  |  |  |  |  |  |  |  | 0.1473

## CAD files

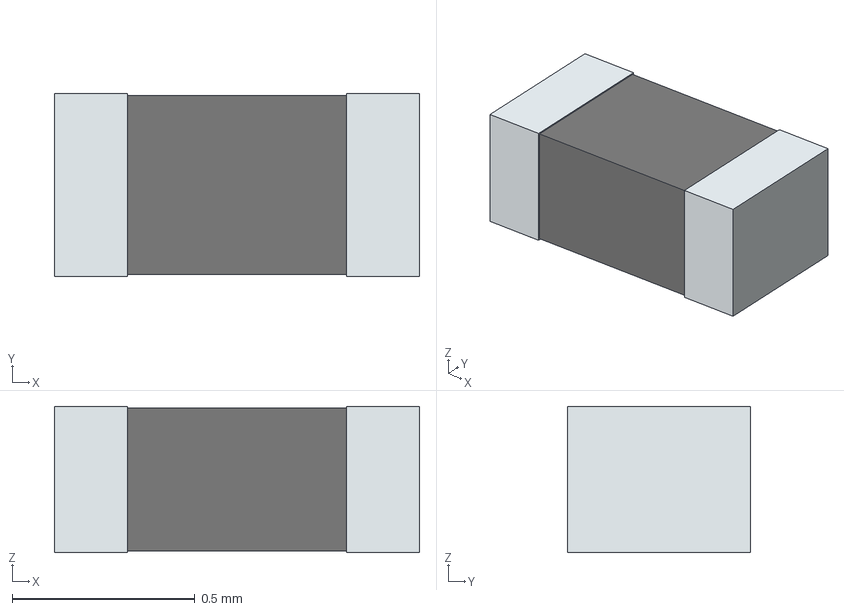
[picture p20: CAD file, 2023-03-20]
PCB/SCHEMATICS/footprint/JLC2KiCad_lib/footprint/0ohm/0402WGF0000TCE/3D/0402WGF0000TCE.stp
1.00 x 0.5 x 0.4 mm
term1
term2

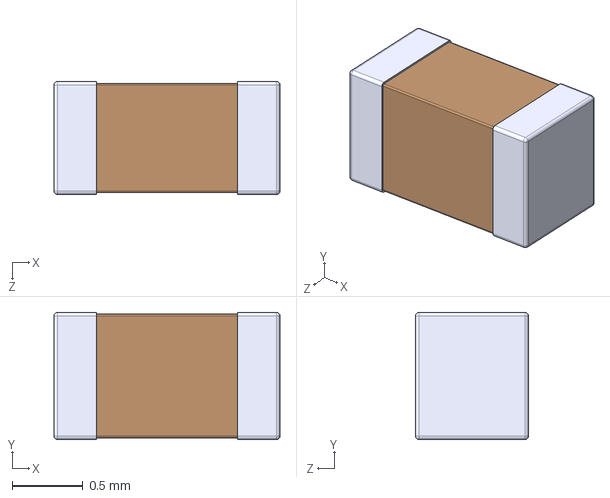
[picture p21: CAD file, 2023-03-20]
PCB/SCHEMATICS/footprint/JLC2KiCad_lib/footprint/10UF/CL10A106KP8NNNC.step
1.60 x 0.9 x 0.8 mm

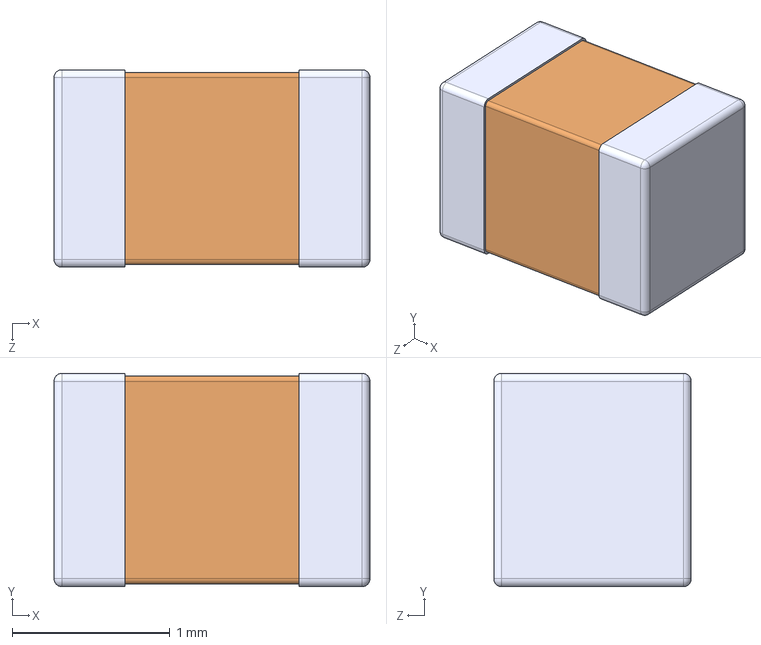
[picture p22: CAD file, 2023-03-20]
PCB/SCHEMATICS/footprint/JLC2KiCad_lib/footprint/1UF/CL21B105KBFNNNE.step
2.00 x 1.35 x 1.25 mm

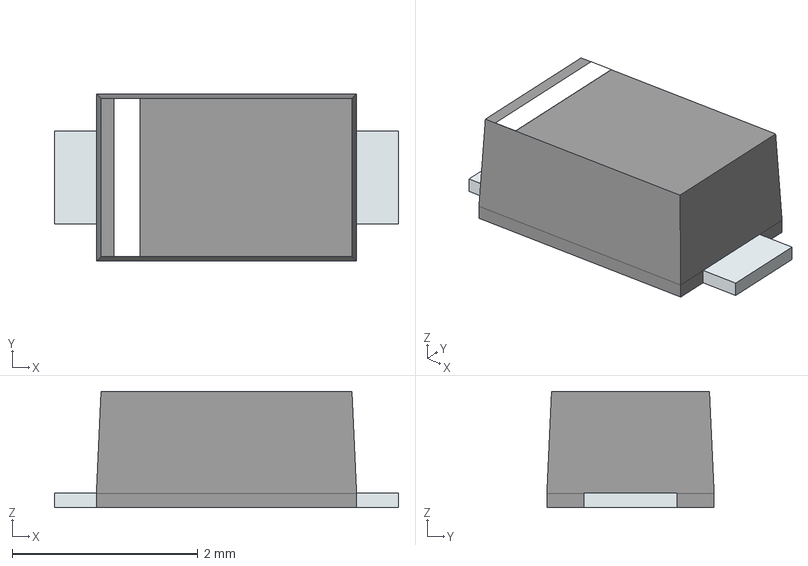
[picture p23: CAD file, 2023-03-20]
PCB/SCHEMATICS/footprint/JLC2KiCad_lib/footprint/diode reg/SM4007PL/3D/SM4007PL.stp
3.70 x 1.80 x 1.25 mm
PinKIdent
PinK
PinA

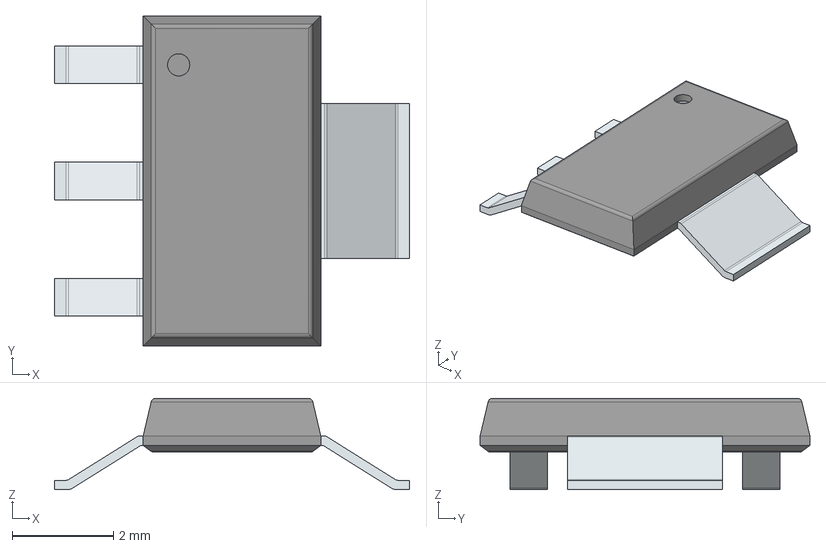
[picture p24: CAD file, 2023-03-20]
PCB/SCHEMATICS/footprint/JLC2KiCad_lib/footprint/LIB_AMS1117-3.3/AMS1117-3.3/3D/AMS1117-3.3.stp
7.00 x 6.50 x 1.80 mm
PinsArrayL
FilletPinR

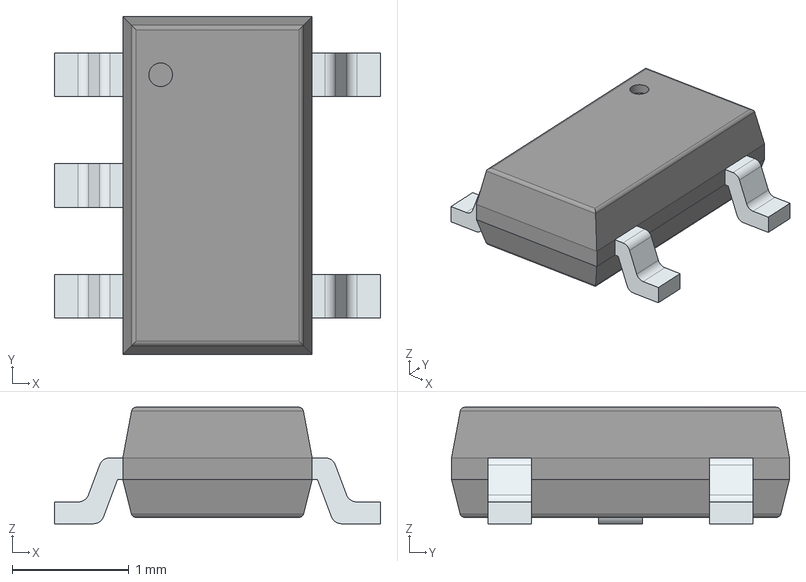
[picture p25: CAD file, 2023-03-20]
PCB/SCHEMATICS/footprint/JLC2KiCad_lib/footprint/LIB_TP4054-42-SOT25-R/TP4054-42-SOT25-R/3D/TP4054-42-SOT25-R.stp
2.80 x 2.90 x 1.00 mm
PinsArrayL
PinsArrayR

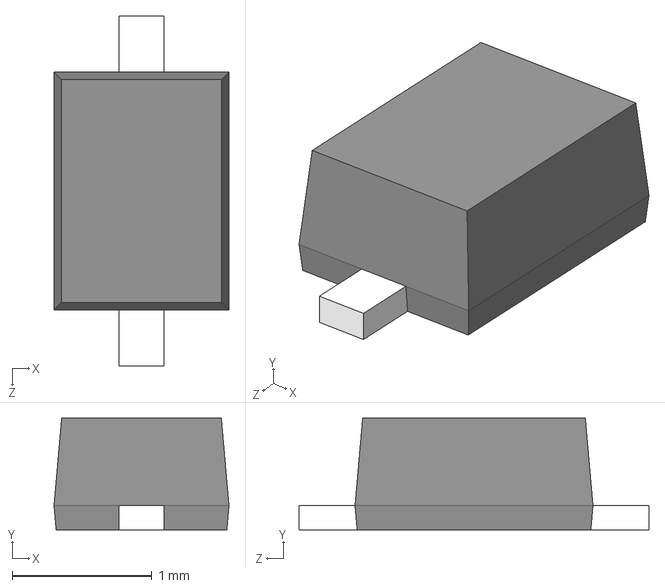
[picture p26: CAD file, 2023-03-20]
PCB/SCHEMATICS/footprint/JLC2KiCad_lib/footprint/SCHOTTKY/PMEG6010CEJ.step
1.25 x 0.8 x 2.50 mm

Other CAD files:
PCB/SCHEMATICS/footprint/JLC2KiCad_lib/footprint/0ohm/0402WGF0000TCE/Allegro/resc1005x40n.psm
PCB/SCHEMATICS/footprint/JLC2KiCad_lib/footprint/0ohm/0402WGF0000TCE/DEHDL/0402wgf0000tce/chips/chips.prt
PCB/SCHEMATICS/footprint/JLC2KiCad_lib/footprint/2.2k/0402WGF0000TCE/Allegro/resc1005x40n.psm
PCB/SCHEMATICS/footprint/JLC2KiCad_lib/footprint/2.2k/0402WGF0000TCE/DEHDL/0402wgf0000tce/chips/chips.prt
PCB/SCHEMATICS/footprint/JLC2KiCad_lib/footprint/LIB_AMS1117-3.3/AMS1117-3.3/Allegro/sot229p700x180-4n.psm
PCB/SCHEMATICS/footprint/JLC2KiCad_lib/footprint/LIB_AMS1117-3.3/AMS1117-3.3/DEHDL/ams1117_3.3/chips/chips.prt
PCB/SCHEMATICS/footprint/JLC2KiCad_lib/footprint/LIB_TP4054-42-SOT25-R/TP4054-42-SOT25-R/Allegro/sot95p280x100-5n.psm
PCB/SCHEMATICS/footprint/JLC2KiCad_lib/footprint/LIB_TP4054-42-SOT25-R/TP4054-42-SOT25-R/DEHDL/tp4054_42_sot25_r/chips/chips.prt
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

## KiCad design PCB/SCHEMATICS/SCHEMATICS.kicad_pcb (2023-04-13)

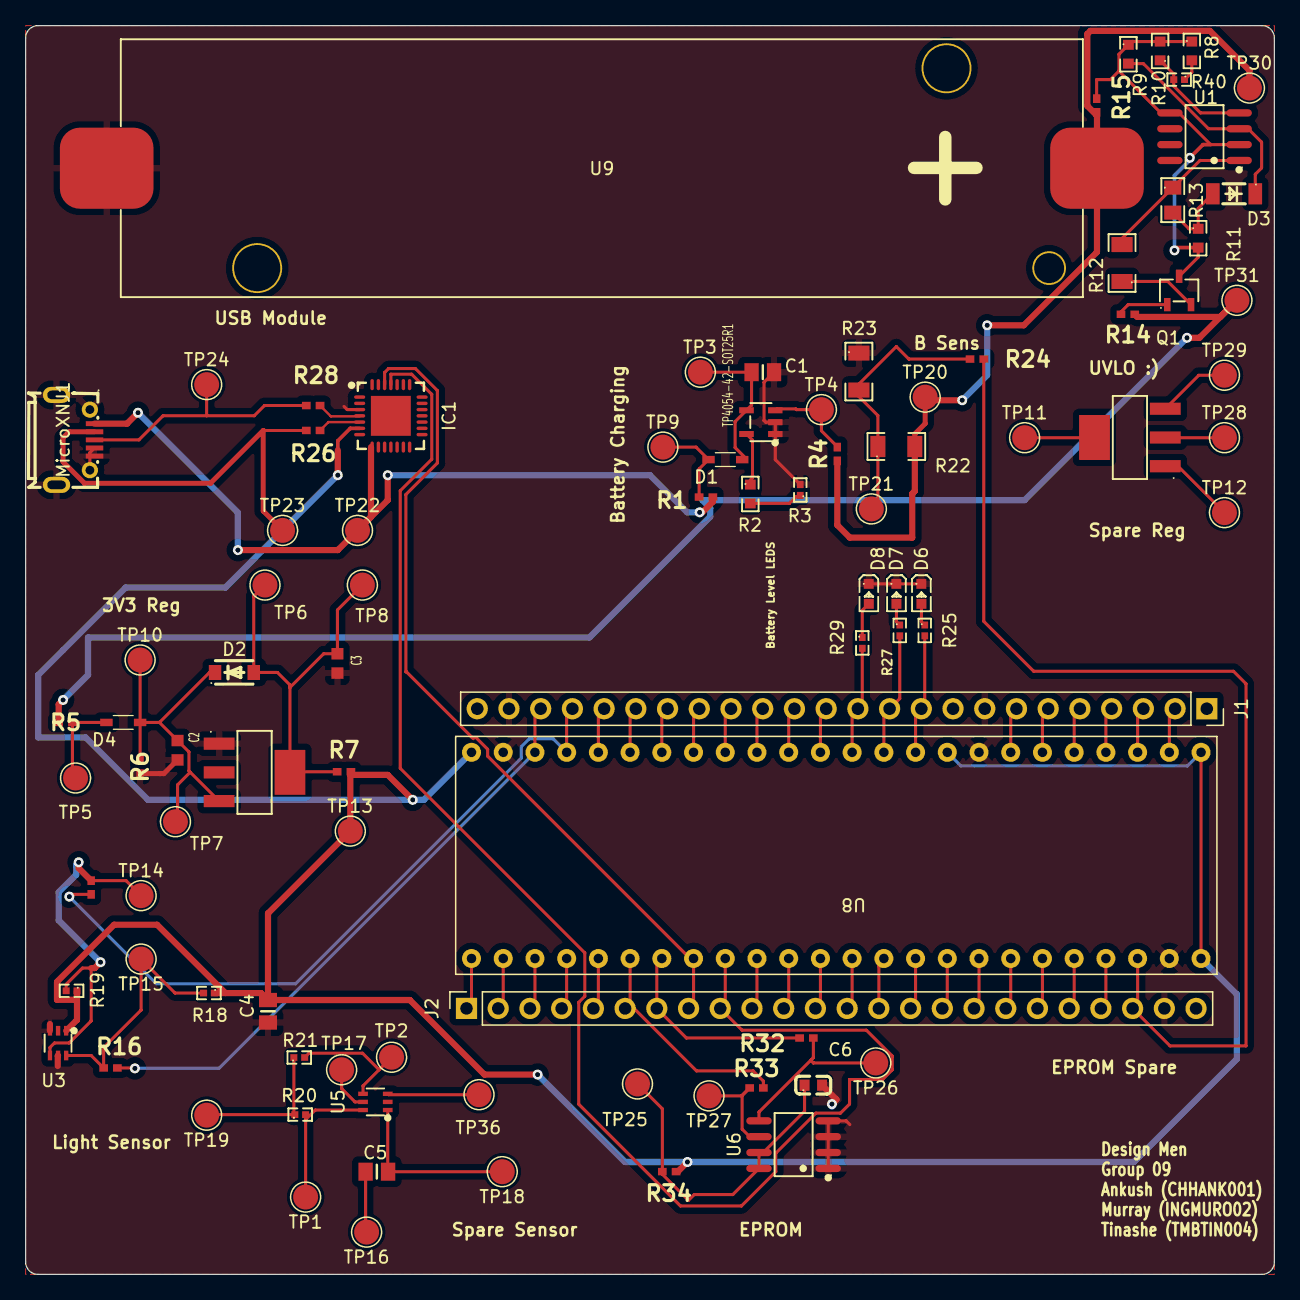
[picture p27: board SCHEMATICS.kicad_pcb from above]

Board: 2 copper layers, 100.0 x 100.0 mm, 92 parts (0 on the bottom side), 86 nets.

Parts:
C1, C4, C5: 1uF; CAPC2012X140N
C2, C3: 10uF; CAPC1608X90N
C6: 3.3nF; C0603
D1, D4: D_Schottky; SOT323_INFINEON
D2: 1N4001; SOD-123F_L2.8-W1.8-LS3.7-RD
D3: D_Zener; LL-34_L3.5-W1.5-RD
D6, D7, D8: LED; LED0603-RD
IC1: CP2102-GMR; WQFN-28_L5.0-W5.0-P0.50-BL-EP3.2
J1, J2: Conn_01x24_Pin; PinSocket_1x24_P2.54mm_Vertical
MicroXNJ1: MICRO-USB-SMD_MICROXNJ
Q1: PMOS; SOT-23-3_L3.0-W1.6-P1.90-LS2.8-BR
R1, R4, R5, R7, R14, R15, R16, R17, R24, R26, R28, R32, R33, R34: 0; RESC1005X40N
R2: 150; R0603
R3: 1.5k; R0402
R6: 2.2k; RESC1005X40N
R8, R10: 3M; R0603
R9: 2.0M; R0603
R11: 150k; R0603
R12: 1M; R1206
R13: 10M; R0805
R18, R19, R20, R21, R25, R27, R29: 1k; R0402
R22, R23: 100k; R1206
R40: Value: Value: Value: Value: Value: Value: 510k; R0402
REF1, REF2: AMS1117-3_3_C369933; SOT-223-4_L6.5-W3.5-P2.30-LS7.0-BR
TP1, TP2, TP3, TP4, TP5, TP6, TP7, TP8, TP9, TP10, TP11, TP12, TP13, TP14, TP15, TP16, TP17, TP18, TP19, TP20, TP21, TP22, TP23, TP24, TP25, TP26, TP27, TP28, TP29, TP30, TP31, TP36: TestPoint; TestPoint_Pad_D2.0mm
TP4054-42-SOT25R1: SOT-23-5_L3.0-W1.7-P0.95-LS2.8-BL
U1: C7433; SOIC-8_L4.9-W3.9-P1.27-LS6.0-BL
U3, U5: LTR-303ALS-01; SOT-363_L2.0-W1.3-P0.65-LS2.1-BL
U6: C6482; SOIC-8_L4.9-W3.9-P1.27-LS6.0-BL
U8: STM32F051C6T6
U9: 18650_Holder_SMD

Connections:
/MICROCONTROLLER/5V: IC1.8 (VBUS), MicroXNJ1.1 (VBUS), R1.1, TP22.1
/MICROCONTROLLER/BOOT: J2.20, U8.44 (BOOT)
/MICROCONTROLLER/D+: IC1.4 (D+), R28.2
/MICROCONTROLLER/D-: IC1.5 (D-), R26.2
/MICROCONTROLLER/NRST: J1.7, U8.7 (NRST)
/MICROCONTROLLER/PA0: J1.10, R25.2, U8.10 (PA0)
/MICROCONTROLLER/PA1: J1.11, R27.2, U8.11 (PA1)
/MICROCONTROLLER/PA2: J1.12, R29.2, U8.12 (PA2)
/MICROCONTROLLER/PA3: J1.13, U8.13 (PA3)
/MICROCONTROLLER/PA4: J1.14, U8.14 (PA4)
/MICROCONTROLLER/PA5: J1.15, U8.15 (PA5)
/MICROCONTROLLER/PA6: J1.16, U8.16 (PA6)
/MICROCONTROLLER/PA7: J1.17, U8.17 (PA7)
/MICROCONTROLLER/PA8: J2.5, U8.29 (PA8)
/MICROCONTROLLER/PA9: J2.6, R33.2, U8.30 (PA9)
/MICROCONTROLLER/PA10: J2.7, R32.2, U8.31 (PA10)
/MICROCONTROLLER/PA11: IC1.26 (TXD), J2.8, U8.32 (PA11)
/MICROCONTROLLER/PA12: IC1.25 (RXD), J2.9, U8.33 (PA12)
/MICROCONTROLLER/PA13: J2.10, U8.34 (PA13)
/MICROCONTROLLER/PA14: J2.13, U8.37 (PA14)
/MICROCONTROLLER/PA15: J2.14, U8.38 (PA15)
/MICROCONTROLLER/PB0: J1.18, U8.18 (PB0)
/MICROCONTROLLER/PB1: J1.19, U8.19 (PB1)
/MICROCONTROLLER/PB2: J1.20, U8.20 (PB2)
/MICROCONTROLLER/PB3: J2.15, U8.39 (PB3)
/MICROCONTROLLER/PB4: J2.16, U8.40 (PB4)
/MICROCONTROLLER/PB5: J2.17, U8.41 (PB5)
/MICROCONTROLLER/PB6: J2.18, U8.42 (PB6)
/MICROCONTROLLER/PB7: J2.19, U8.43 (PB7)
/MICROCONTROLLER/PB8: J2.21, U8.45 (PB8)
/MICROCONTROLLER/PB9: J2.22, R24.2, U8.46 (PB9)
/MICROCONTROLLER/PB10: J1.21, R17.1, U8.21 (PB10)
/MICROCONTROLLER/PB11: J1.22, R16.1, U8.22 (PB11)
/MICROCONTROLLER/PB12: J2.1, U8.25 (PB12)
/MICROCONTROLLER/PB13: J2.2, U8.26 (PB13)
/MICROCONTROLLER/PB14: J2.3, U8.27 (PB14)
/MICROCONTROLLER/PB15: J2.4, U8.28 (PB15)
/MICROCONTROLLER/PC13: J1.2, U8.2 (PC13)
/MICROCONTROLLER/PC14: J1.3, U8.3 (PC14)
/MICROCONTROLLER/PC15: J1.4, U8.4 (PC15)
/MICROCONTROLLER/PF0: J1.5, U8.5 (PF0)
/MICROCONTROLLER/PF1: J1.6, U8.6 (PF1)
/MICROCONTROLLER/PF6: J2.11, U8.35 (PF6)
/MICROCONTROLLER/PF7: J2.12, U8.36 (PF7)
/MICROCONTROLLER/VSS: C4.2, IC1.6 (VDD), R7.2, R18.1, R19.1, R34.2, TP13.1, U3.1 (VDD), U8.1 (VBAT), U8.9 (V+), U8.24 (V+), U8.48 (V+)
/POWER MODULE/Battery: R4.2, R15.1, R22.2, TP20.1, TP30.1, U9.1 (+)
/POWER MODULE/UVLO Output: R5.1, R14.2, TP31.1
GND: C1.2, C2.2, C3.2, C4.1, C6.2, D6.1 (K), D7.1 (K), D8.1 (K), IC1.3 (GND), J1.8, J1.23, J2.23, MicroXNJ1.4 (ID), MicroXNJ1.5 (GND), MicroXNJ1.6 (SH1), MicroXNJ1.7 (SH2), MicroXNJ1.8 (SH3), MicroXNJ1.9 (SH4), R3.2, R6.2, R23.1, REF1.1 (GND/ADJ), TP4054-42-SOT25R1.1 (~CHRG), TP4054-42-SOT25R1.2 (GND), U3.3 (GND), U3.5 (INT), U6.1 (A0), U6.2 (A1), U6.3 (A2), U6.4 (GND), U8.8 (GND), U8.23 (GND), U8.47 (GND), U9.2 (-)
unnamed: C2.1, D2.1 (K), D4.C (K), R6.1, REF1.3 (Input), TP7.1, TP10.1
unnamed: Q1.3 (S), R8.1, R9.1, R10.2, R11.2, R15.2, U1.2 (V-), U1.5 (V+)
unnamed: C5.1, TP16.1
unnamed: C1.1, D1.C (K), TP3.1, TP4054-42-SOT25R1.4 (VCC)
unnamed: D1.A, R1.2, TP9.1
unnamed: C3.1, D2.2 (A), R7.1, REF1.4 (Output), TP6.1, TP8.1
unnamed: D3.2 (A), R11.1, R13.2
unnamed: D3.1 (K), R9.2, U1.3 (+)
unnamed: D4.A, R5.2, TP5.1
unnamed: D6.2 (A), R25.1
unnamed: D7.2 (A), R27.1
unnamed: D8.2 (A), R29.1
unnamed: MicroXNJ1.3 (D+), R28.1, TP24.1
unnamed: MicroXNJ1.2 (D-), R26.1, TP23.1
unnamed: Q1.1 (D), R14.1
unnamed: Q1.2 (G), R12.1
unnamed: R2.2, R3.1
unnamed: R12.2, R13.1, U1.1
unnamed: R20.1, R21.1, TP19.1
unnamed: R22.1, R23.2, R24.1, TP21.1
unnamed: R8.2, R40.1
unnamed: REF2.1 (GND/ADJ), TP12.1
unnamed: REF2.3 (Input), TP29.1
unnamed: REF2.2 (Output), TP28.1
unnamed: REF2.4 (Output), TP11.1
unnamed: R4.1, TP4.1, TP4054-42-SOT25R1.3 (BAT)
unnamed: R2.1, TP4054-42-SOT25R1.5 (PROG)
unnamed: R10.1, R40.2, U1.4 (-)
unnamed: R17.2, R19.2, TP14.1, U3.4 (SCL)
unnamed: R16.2, R18.2, TP15.1, U3.6 (SDA)
unnamed: TP36.1, U5.3 (GND)
unnamed: TP17.1, U5.5 (INT)
unnamed: R21.2, TP2.1, U5.4 (SCL)
unnamed: R20.2, TP1.1, U5.6 (SDA)
unnamed: C5.2, TP18.1, U5.1 (VDD)
unnamed: R33.1, TP27.1, U6.6 (SCL)
unnamed: R32.1, TP26.1, U6.5 (SDA)
unnamed: C6.1, R34.1, U6.7 (WP), U6.8 (VCC)

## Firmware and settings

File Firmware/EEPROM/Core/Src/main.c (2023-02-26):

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
/* Includes ------------------------------------------------------------------*/
#include "main.h"

/* USER CODE BEGIN Includes */
#include "string.h"
#include "stm32f0xx_hal.h"

/* USER CODE END Includes */

/* USER CODE BEGIN PD */
#define DELAY 1000
/* USER CODE END PD */

I2C_HandleTypeDef hi2c1;
UART_HandleTypeDef huart2;

/* USER CODE BEGIN PV */
//static const uint8_t EEPROM_ADDR_R = 0xAB; // 1010 (Required by chip), 1011 (As wired on my board: A2 A1 A0 + R)
//static const uint8_t EEPROM_ADDR_W = 0xAA; // 1010 (Required by chip), 1010 (As wired on my board: A2 A1 A0 + !W)
/* USER CODE END PV */

void SystemClock_Config(void);
static void MX_GPIO_Init(void);
static void MX_USART2_UART_Init(void);
static void MX_I2C1_Init(void);
/* USER CODE BEGIN 0 */
//Global variables
//General purpose Function to send a char array over the UART and to automatically send a new line character after it
void debugPrintln(UART_HandleTypeDef *uart_handle, char _out[]) {
	HAL_UART_Transmit(uart_handle, (uint8_t*) _out, strlen(_out), 60);
	char newline[2] = "\r\n";
	HAL_UART_Transmit(uart_handle, (uint8_t*) newline, 2, 10);
}
/* USER CODE END 0 */

/**
 * @brief  The application entry point.
 * @retval int
 */
int main(void) {
	/* MCU Configuration--------------------------------------------------------*/

	/* Reset of all peripherals, Initializes the Flash interface and the Systick. */
	HAL_Init();

	/* Configure the system clock */
	SystemClock_Config();

	/* Initialize all configured peripherals */
	MX_GPIO_Init();
	MX_USART2_UART_Init();
	MX_I2C1_Init();

	/* USER CODE BEGIN 2 */
	char str[60] = { 0 }; //Useful buffer for printing to UART
	uint8_t I2CReturn = 0; //Status var to indicate if HAL_I2C operation has succeeded (1) or failed (0);
	uint8_t i, j, Loop = 0; //Loop counters

	//Setup variables for reading and writing
	uint16_t EEPROM_DEVICE_ADDR = 0x55 << 1; //Address of EEPROM device on I2C bus
	uint16_t madd = 0x00; //Memory address variable containing a starting memory address for a location of memory in the EEPROM
	uint8_t Data = 0x10;//Data variable containing sStarting value to write to memory, could be any 8bit value
	uint8_t *sData = &Data;	//Pointer to sending Data variable
	uint8_t Result = 0x00;	//Variable to stored value read back from memory in
	uint8_t *rData = &Result;	//Pointer to result data variable

	/* USER CODE END 2 */

	/* Infinite loop */

	/* USER CODE BEGIN WHILE */

	//Say hello over UART
	debugPrintln(&huart2, "Hello, this is STMF0 Discovery board: ");

	while (1) {

		//Print and increment a loop counter for visual tracking/debugging purposes only
		memset(str, 0, sizeof(str));	//Reset str to zeros
		sprintf(str, "\rLoop count %d\n", Loop);//Format string to include the loop counter variable
		debugPrintln(&huart2, str);
		Loop = Loop + 1;

		//Write and read back 5 different values to 5 different memory locations
		for (i = 0; i < 5; i++) {
			//WRITING
			memset(str, 0, sizeof(str));
			sprintf(str, "Writing 0x%X to EEPROM address 0x%X", Data, madd);
			debugPrintln(&huart2, str);

			I2CReturn = HAL_I2C_Mem_Write(&hi2c1, EEPROM_DEVICE_ADDR, madd, 2,
					sData, 1, HAL_MAX_DELAY);
			if (I2CReturn != HAL_OK) {
				debugPrintln(&huart2, "Write to address FAILED");
			}

			//READING
			memset(str, 0, sizeof(str));
			sprintf(str, "Reading from EEPROM address 0x%X ", madd);
			debugPrintln(&huart2, str);

			I2CReturn = HAL_I2C_Mem_Read(&hi2c1, EEPROM_DEVICE_ADDR, madd, 2,
					rData, 1, HAL_MAX_DELAY);
			if (I2CReturn != HAL_OK) {
				debugPrintln(&huart2, "Read from address FAILED");
			}

			//PRINT READ VALUE
			memset(str, 0, sizeof(str));
			sprintf(str, "Received data: 0x%X \n", Result);
			debugPrintln(&huart2, str);

			//Increment address and data values and clear Result holder
			madd = madd + 1;
			Data = Data + 1;
			Result = 0x00;
			HAL_Delay(1000);  //Pause
		}

		//Read back last 5 values again:
		madd = madd - 5;
		for (j = 0; j < 5; j++) {

			I2CReturn = HAL_I2C_Mem_Read(&hi2c1, EEPROM_DEVICE_ADDR, madd, 2,
					rData, 1, HAL_MAX_DELAY);
			if (I2CReturn != HAL_OK) {
				debugPrintln(&huart2, "Read from address FAILED");
			}

			//PRINT READ VALUE
			memset(str, 0, sizeof(str));
			sprintf(str, "Address 0x%X contains: 0x%X ", madd, Result);
			debugPrintln(&huart2, str);

			madd = madd + 1;
		}
		debugPrintln(&huart2, "-------------");

		//Flash Blue LED
		HAL_GPIO_TogglePin(GPIOC, GPIO_PIN_8);
		HAL_Delay(DELAY);
		/* USER CODE END WHILE */

		/* USER CODE BEGIN 3 */
	}
	/* USER CODE END 3 */
}

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


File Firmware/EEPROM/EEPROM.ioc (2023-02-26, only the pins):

Mcu.UserName=STM32F051R8Tx
PA2.Signal=USART2_TX
PA3.Signal=USART2_RX
PB6.Signal=I2C1_SCL
PB7.Signal=I2C1_SDA
PC8.Signal=GPIO_Output

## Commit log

2023-02-26 Updated repo using template
    [example1_libraries.kicad_pcb, example1_libraries.kicad_sch, main.kicad_pcb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]
2023-03-04 uploaded initial designs
    [EE3088.kicad_pcb, EE3088.kicad_sch, MICROCONTROLLER.kicad_sch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]
2023-03-05 Formatting folder
    [MICROCONTROLLER.kicad_sch, SCHEMATICS.kicad_pcb, SCHEMATICS.kicad_sch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]
2023-03-05 Updated Schematics
    [EE3088.kicad_pcb, EE3088.kicad_sch, MICROCONTROLLER.kicad_sch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]
2023-03-05 UPDATED SCHEMATICS.
    [MICROCONTROLLER.kicad_sch, SENSING.kicad_sch, untitled.kicad_sch]
2023-03-05 Added BOM
    [BOM.xlsx]
2023-03-10 Updating schematics
    [SENSING.kicad_sch]
2023-03-10 Name changes
    [SCHEMATICS.kicad_sch]
2023-03-11 Adjusted Schematics
    [MICROCONTROLLER.kicad_sch, POWER_MODULE.kicad_sch, SENSING.kicad_sch]
2023-03-12 Updated BOM
    [MICROCONTROLLER.kicad_sch, POWER_MODULE.kicad_sch, SENSING.kicad_sch]
2023-03-12 Updated BOM CSV
    [SCHEMATICS.csv]
2023-03-12 Updated Micro schematic
    [MICROCONTROLLER.kicad_sch]
2023-03-12 BOM updated
    [BOM.xlsx]
2023-03-13 Finalizing week 4 document
    [MICROCONTROLLER.kicad_sch]
2023-03-13 Updating EEPROM part no
    [MICROCONTROLLER.kicad_sch]
2023-03-13 Adding bom to document
    [MICROCONTROLLER.kicad_sch]
2023-03-17 Importing footprints for microcontroller
    [MICROCONTROLLER.kicad_sch]
2023-03-18 Updating symbols and footprints
    [MICROCONTROLLER.kicad_sch, untitled.kicad_sch]
2023-03-19 Added footprints
    [Copy of BOM(10722).xlsx, MICROCONTROLLER.kicad_sch, POWER_MODULE.kicad_sch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]
2023-03-19 Trying to merge
    [MICROCONTROLLER.kicad_sch]
2023-03-19 Cleaning up
    [HAT.kicad_pcb, HAT.sch, power.sch]
2023-03-19 updated schematics and footprints
    [MICROCONTROLLER.kicad_sch, POWER_MODULE.kicad_sch, SENSING.kicad_sch]
2023-03-19 Added sim lib table
    [MICROCONTROLLER.kicad_sch, POWER_MODULE.kicad_sch, SENSING.kicad_sch]
2023-03-19 Added stm
    [MICROCONTROLLER.kicad_sch, POWER_MODULE.kicad_sch, SENSING.kicad_sch]
2023-03-19 Added battery
    [POWER_MODULE.kicad_sch]
2023-03-19 Fixed ercs
    [MICROCONTROLLER.kicad_sch, POWER_MODULE.kicad_sch, SCHEMATICS.kicad_sch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]
2023-03-19 Fixing ERCs
    [MICROCONTROLLER.kicad_sch, POWER_MODULE.kicad_sch, SCHEMATICS.kicad_sch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]
2023-03-19 Added pwr flags
    [POWER_MODULE.kicad_sch]
2023-03-19 Started PCB design
    [MICROCONTROLLER.kicad_sch, POWER_MODULE.kicad_sch, SCHEMATICS.kicad_pcb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]
2023-03-20 updated path for footprints
    [0402WGF0000TCE.SchLib, 0402WGF0000TCE.stp, AMS1117-3.3.SchLib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]
2023-03-20 Fixed warning in PCB editor
    [POWER_MODULE.kicad_sch, SCHEMATICS.kicad_pcb]
2023-03-20 Creating ratsnest
    [SCHEMATICS.kicad_pcb]
2023-03-20 RATS NEST START
    [SCHEMATICS.kicad_pcb]
2023-03-20 Added traces
    [MICROCONTROLLER.kicad_sch, POWER_MODULE.kicad_sch, SCHEMATICS.kicad_pcb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]
2023-03-20 Updating PCB
    [SCHEMATICS.kicad_pcb]
2023-03-20 Added parallel headers and edge cuts
    [MICROCONTROLLER.kicad_sch, SCHEMATICS.kicad_pcb]
2023-03-20 updated traces
    [SCHEMATICS.kicad_pcb]
2023-03-20 Updated pcb
    [MICROCONTROLLER.kicad_sch, POWER_MODULE.kicad_sch, SCHEMATICS.kicad_pcb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]
2023-03-21 Made changes
    [POWER_MODULE.kicad_sch, SCHEMATICS.kicad_pcb, SCHEMATICS.kicad_sch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]
2023-03-21 Labeled modules
    [MICROCONTROLLER.kicad_sch, POWER_MODULE.kicad_sch, SCHEMATICS.kicad_pcb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]
2023-03-21 added gerbers and BOM
    [BOMJLC.xlsx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]
2023-04-04 Added final docs
    [BOMJLC-submission.xlsx, BOMJLC.xlsx, MICROCONTROLLER.kicad_sch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]
2023-04-13 Justins reccomendations
    [MICROCONTROLLER.kicad_sch, POWER_MODULE.kicad_sch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]
2023-04-13 Bom update
    [BOMJLC-submission.xlsx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]
2023-04-24 added some totals and fixed some grammar issure in report
    [BOMJLC-submission.csv, BOMJLC-submission.xlsx, Postion file.csv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]

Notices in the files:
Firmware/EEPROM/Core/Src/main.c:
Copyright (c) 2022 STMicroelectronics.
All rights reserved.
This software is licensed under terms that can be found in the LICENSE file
